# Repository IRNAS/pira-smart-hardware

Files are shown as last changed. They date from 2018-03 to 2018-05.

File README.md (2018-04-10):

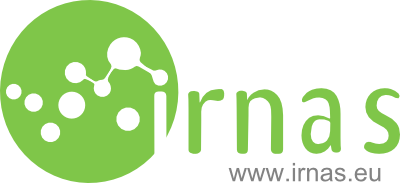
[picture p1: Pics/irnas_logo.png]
irnas_logo

# PiRa Smart
## Power in Responsive Applications HAT for Raspberry Pi with BLE, LoRa and RTC for power saving mode
PiRa Smart is a next generation compact shield for power scheduling on Rasppbery Pi and similar devices with solar and wirelessly powered applications.

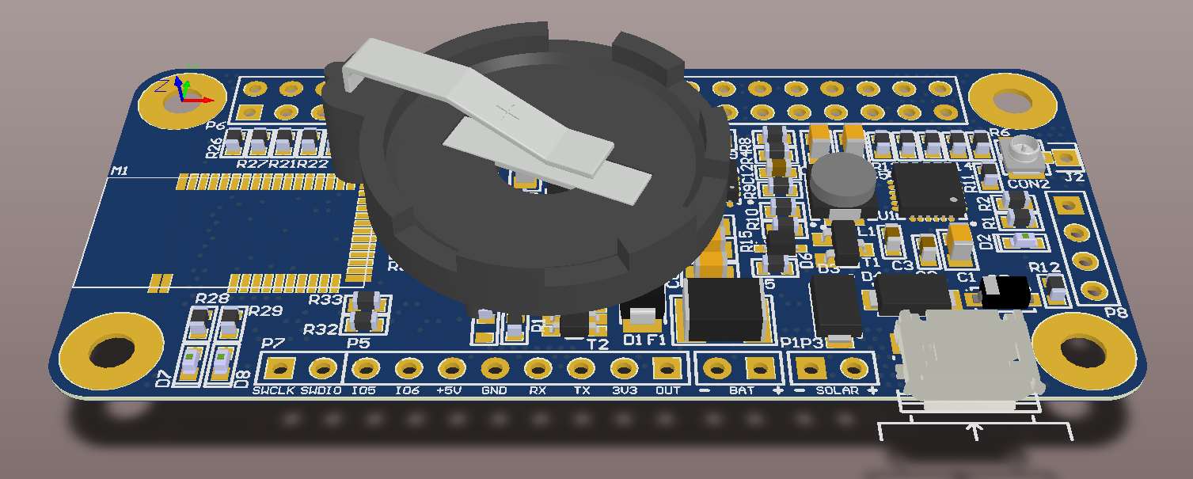
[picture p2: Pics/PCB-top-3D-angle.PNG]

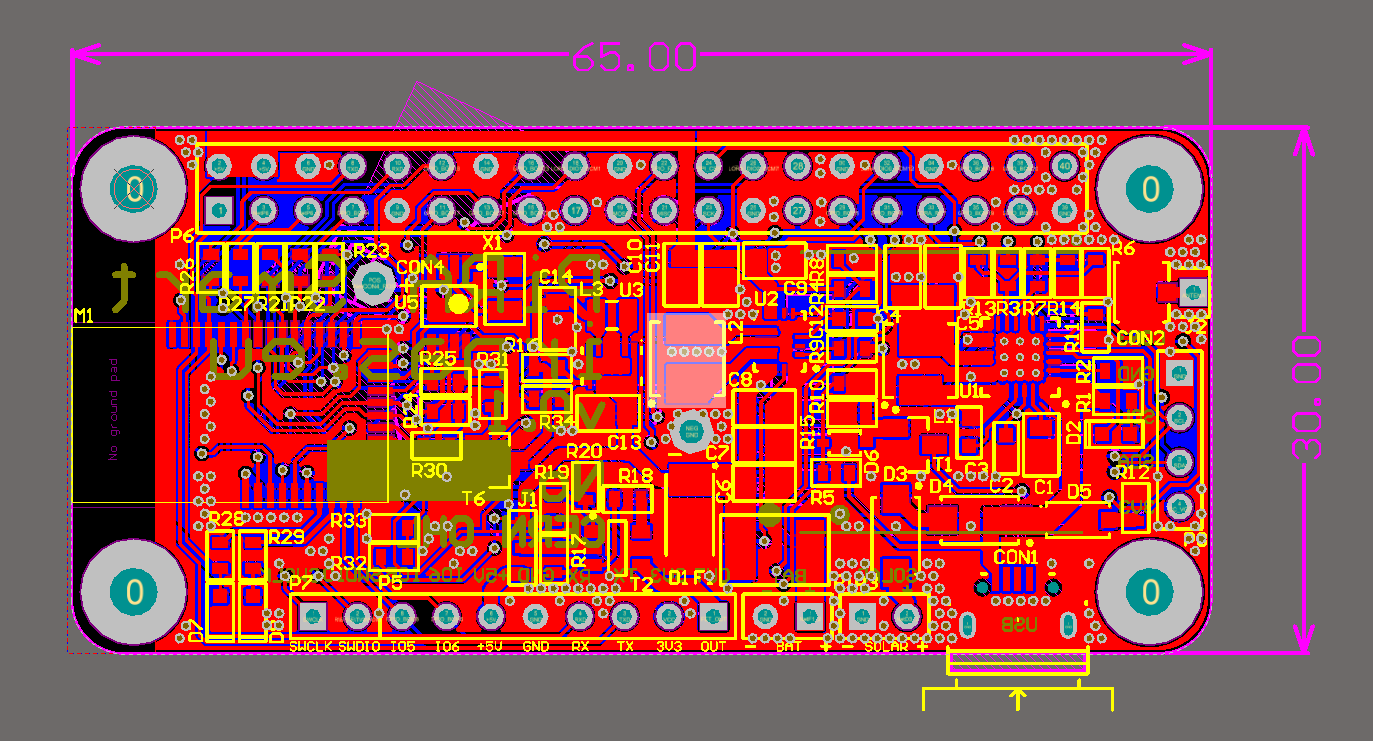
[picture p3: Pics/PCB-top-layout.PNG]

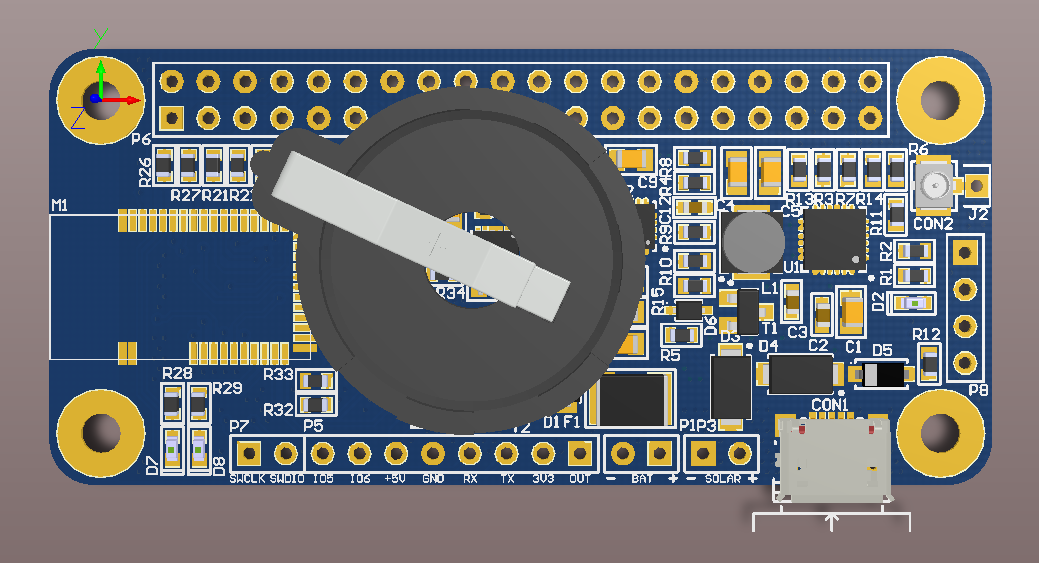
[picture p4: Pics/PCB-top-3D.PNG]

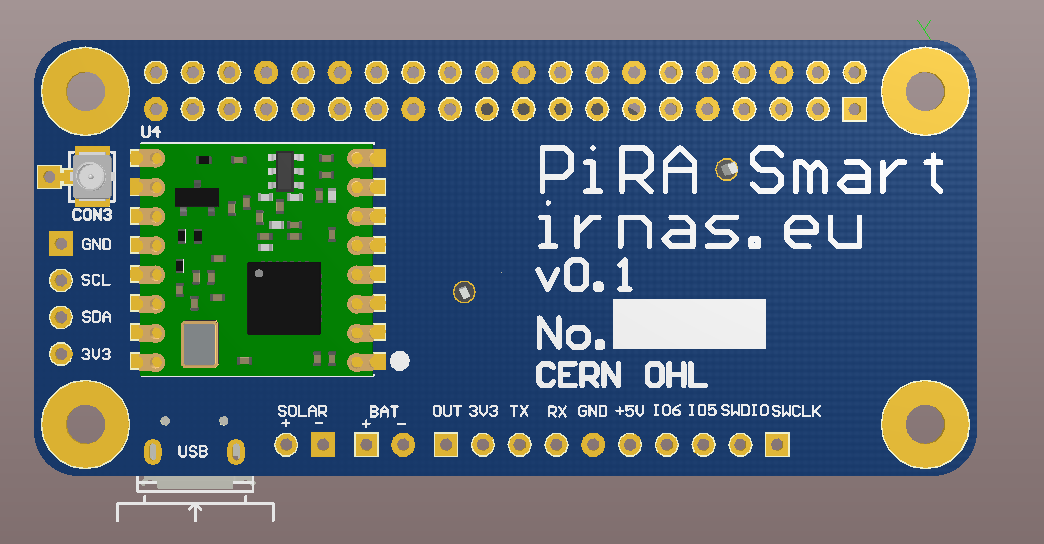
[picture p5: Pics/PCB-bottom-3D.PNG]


## Features

* Single cell LiPo cell charging of up to 3A (multiple 18650 cells supported) + LifePo4 support
* Solar panel charging (Voltaic systems 6W panels in parallel recommended)
* USB charging, compatible with QI wireless chargers
* Advanced current limiting, to support wide array of chargers
* Precise charging control via i2c (BQ24296)
* Battery temperature protection with thermistor
* Battery reverse polarity protection and fuse (3A)
* High-current battery output mosfet (for 3G or satellite modems)
* LoRa RMF95 communication module
* Nordic nRF51822 based BLE device for FOTA (Firmware Over-The-Air update) and control (MDBT40)
* Advanced power scheduling for robust applications:
  * ISL1208 RTC for configurable scheduled boot and timekeeping, with battery backup power supply to save power of the main battery
  * configurable power-up sources (RTC, charging, etc.)
 
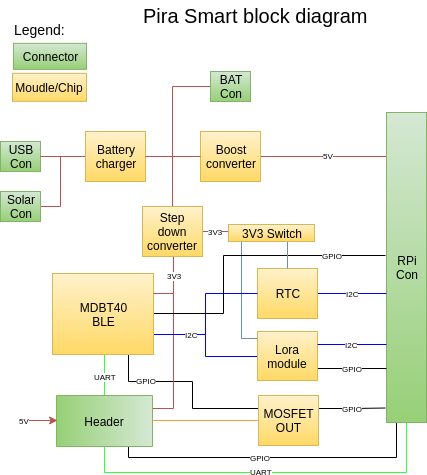
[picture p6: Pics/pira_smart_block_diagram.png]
pira_block_diagram


## Connector pinout

 * All ground pins connected
 * Pin 1 -  3V3 - Not Used
 * Pin 2 -  5V - From board to Pi
 * Pin 3 -  SDA - Connected to MDBT40 and other I2C devices through 0R resistors
 * Pin 4 -  5V - From board to Pi
 * Pin 5 -  SCL - Connected to MDBT40 and other I2C devices through 0R resistors
 * Pin 7 -  GPIO BCM 4 - Connected to MDBT40, P0.24
 * Pin 8 -  TXD - Connected to Header P5 (pin 3) and MDBT40, P0.18
 * Pin 10 - RXD - Connected to Header P5 (pin 4) and MDBT40, P0.17
 * Pin 11 - GPIO BCM 17 - Connected to MDBT40, P0.25
 * Pin 12 - GPIO BCM 18 - Connected to MDBT40, P0.30
 * Pin 13 - GPIO BCM 27 - Connected to MDBT40, P0.28
 * Pin 15 - GPIO BCM 22 - Connected to MDBT40, P0.29
 * Pin 16 - GPIO BCM 23 - GPIO-FET - Enable MOSFET output and connected to MDBT40, P0.16
 * Pin 17 - Not Connected
 * Pin 18 - GPIO BCM 1  - Connected to LoRa DIO1
 * Pin 19 - MOSI - Connected to RFM95 (LoRa) and MDBT40, P0.05
 * Pin 21 - MISO - Connected to RFM95 (LoRa) and MDBT40, P0.06
 * Pin 22 - GPIO BCM 25 - Connected to MDBT40, P0.15
 * Pin 23 - SCK  - Connected to RFM95 (LoRa) and MDBT40, P0.07
 * Pin 24 - CSS  - Connected to RFM95 (LoRa) and MDBT40, P0.14
 * Pin 26 - GPIO BCM 7 - Connected to LoRa DIO2
 * Pin 27 - Not Connected
 * Pin 28 - Not Connected
 * Pin 29 - GPIO BCM 5  - Connected to Header P5 (pin 7) and MDBT40, P0.10
 * Pin 31 - GPIO BCM 6  - Connected to Header P5 (pin 8) and MDBT40, P0.09
 * Pin 32 - GPIO BCM 12 - Connected to LoRa DIO0
 * Pin 33 - GPIO BCM 13 - LoRa RESET
 * Pin 35 - GPIO BCM 19 - Connected to MDBT40, P0.01
 * Pin 36 - GPIO BCM 16 - Connected to MDBT40, P0.02
 * Pin 37 - GPIO BCM 26 - Connected to MDBT40, P0.03
 * Pin 38 - GPIO BCM 20 - Connected to MDBT40, P0.04
 * Pin 40 - Not Connected

#### License

All our projects are as usefully open-source as possible.

Hardware including documentation is licensed under [CERN OHL v.1.2. license](http://www.ohwr.org/licenses/cern-ohl/v1.2)

Firmware and software originating from the project is licensed under [GNU GENERAL PUBLIC LICENSE v3](http://www.gnu.org/licenses/gpl-3.0.en.html).

Open data generated by our projects is licensed under [CC0](https://creativecommons.org/publicdomain/zero/1.0/legalcode).

All our websites and additional documentation are licensed under [Creative Commons Attribution-ShareAlike 4 .0 Unported License](https://creativecommons.org/licenses/by-sa/4.0/legalcode).

What this means is that you can use hardware, firmware, software and documentation without paying a royalty and knowing that you'll be able to use your version forever. You are also free to make changes but if you share these changes then you have to do so on the same conditions that you enjoy.

Koruza, GoodEnoughCNC and IRNAS are all names and marks of Institut IRNAS Rače. 
You may use these names and terms only to attribute the appropriate entity as required by the Open Licences referred to above. You may not use them in any other way and in particular you may not use them to imply endorsement or authorization of any hardware that you design, make or sell.

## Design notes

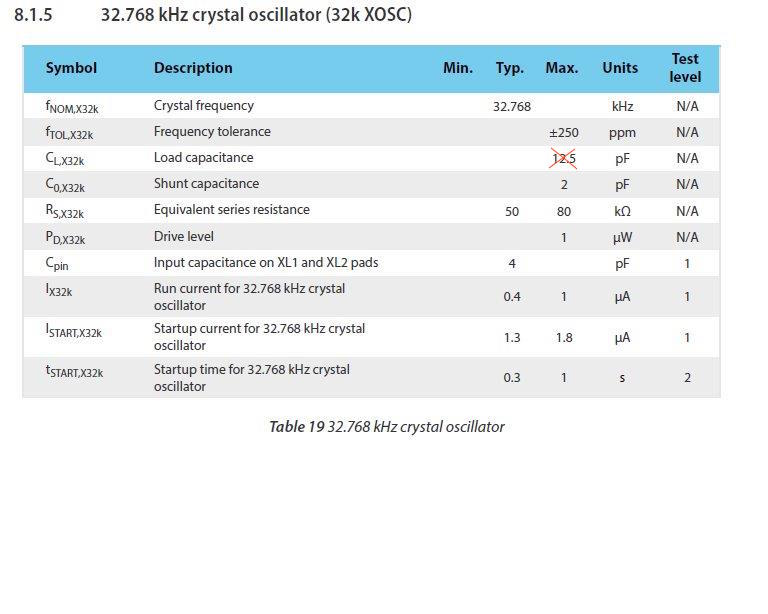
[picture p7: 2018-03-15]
docs/footprint/MDBT40_MDBT40-P Footprint_Design Guide-20170726/Recommended 32.768KHZ Crystal Spec/Nordic Spec Sheet-32.768KHZ.jpg

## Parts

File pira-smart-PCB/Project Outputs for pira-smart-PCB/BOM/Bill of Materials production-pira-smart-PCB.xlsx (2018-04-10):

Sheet: Part List Report
 | Component list |  |  | PiRa-Smart
 | Source Data From: | pira-smart-PCB.PrjPcb |  |  | Contact:
 | Project: | pira-smart-PCB.PrjPcb
 | Variant: | None |  |  |  |  |  |  | IRNAS
 | Report Date: | 4/4/2018 | 12:13:49 PM |  |  |  |  |  | www.irnas.eu
 | Print Date: | 2018-04-04 | 12:14:01
# | Manufacturer Part Number 1 | Manufacturer 1 | Description | Footprint | Designator | Quantity | Supplier 1 | Supplier Part Number 1 | Supplier Order Qty 1 | Supplier Stock 1 | Supplier Unit Price 1 | Supplier Subtotal 1 | Supplier Currency 1
1 | SE30AFG-M3/6A (https://octopart-clicks.com/click/altium?sku=2313878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) | Vishay Semiconductors (https://octopart-clicks.com/click/altium?sku=2313878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) | VISHAY - SE30AFG-M3/6A - RECTIFIER, ESD, 400V, 3A, DO-221AC | SODFL127P600-8N | D3, D4 | 2 | Farnell | 2313878 (https://octopart-clicks.com/click/altium?sku=2313878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) | 8 | 557 | 0.17 | 1.34 | GBP
2 | RS1JE361T (https://octopart-clicks.com/click/altium?sku=9550143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) | Vishay Intertechnology (https://octopart-clicks.com/click/altium?sku=9550143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) | VISHAY - RS1J-E3/61T.. - DIODE, FAST, 1A, 600V, SMD | SMC/DO-214AC | D1 | 1 | Farnell | 9550143 (https://octopart-clicks.com/click/altium?sku=9550143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) | 5 | 5074 | 0.21 | 1.05 | GBP
3 | RCA060310R0FKEA (https://octopart-clicks.com/click/altium?sku=2616585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) | Vishay Dale (https://octopart-clicks.com/click/altium?sku=2616585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) | VISHAY - RCA060310R0FKEA - RES, AUTO, THICK FILM, 10R, 1%, 0603 | RES0603 | R12 | 1 | Farnell | 2616585 (https://octopart-clicks.com/click/altium?sku=2616585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) | 10 | 326 | 0.09 | 0.92 | EUR
4 | BQ24296RGET (https://octopart-clicks.com/click/altium?sku=2373541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) | Texas Instruments (https://octopart-clicks.com/click/altium?sku=2373541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) | IC LI+ CHARGER PWR MGMT 24VQFN | QFN4x4 | U1 | 1 | Farnell | 2373541 (https://octopart-clicks.com/click/altium?sku=2373541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) | 4 | 251 | 2.36 | 9.44 | EUR
5 | TPS630701RNMT (https://octopart-clicks.com/click/altium?sku=2643432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) | Texas Instruments (https://octopart-clicks.com/click/altium?sku=2643432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) | TEXAS INSTRUMENTS - TPS630701RNMT - DC/DC CONV, BUCK-BOOST, 2.4MHZ, VQFN-15 | VQFN TPS | U2 | 1 | Farnell | 2643432 (https://octopart-clicks.com/click/altium?sku=2643432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) | 4 | 170 | 2.58 | 10.32 | EUR
6 | TPS62740DSSR (https://octopart-clicks.com/click/altium?sku=2781752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) | Texas Instruments (https://octopart-clicks.com/click/altium?sku=2781752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) | Voltage Regulators - Switching Regulators 360-nA Iq SD Cnvtr w/ Intg Load Switch | SON50P200X265_HS-13N | U3 | 1 | Farnell | 2781752 (https://octopart-clicks.com/click/altium?sku=2781752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) | 5 | 2312 | 1.44 | 7.20 | EUR
7 | 109990166 (https://octopart-clicks.com/click/altium?sku=1597-1488-ND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) | Seeed Studio (https://octopart-clicks.com/click/altium?sku=1597-1488-ND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) | RFM95 ULTRA-LONG RANGE TRANSCEIV | Lora_module1 | U4 | 1 | Digi-Key | 1597-1488-ND (https://octopart-clicks.com/click/altium?sku=1597-1488-ND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) |  | 0 |  |  | Loading...
8 | MMBT3904 (https://octopart-clicks.com/click/altium?manufacturer=ON%20Semiconductor%20%2F%20Fairchild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) | ON Semiconductor / Fairchild (https://octopart-clicks.com/click/altium?manufacturer=ON%20Semiconductor%20%2F%20Fairchild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) | ON SEMICONDUCTOR/FAIRCHILD - MMBT3904 - TRANSISTOR, NPN, SOT-23 | SOT23127P600-8N | T1 | 1 | Farnell | 9846727 (https://octopart-clicks.com/click/altium?manufacturer=ON%20Semiconductor%20%2F%20Fairchild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) | 5 | 0 | 0.15 | 0.77 | GBP
9 | 2N7002,215 (https://octopart-clicks.com/click/altium?sku=1510761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) | Nexperia (https://octopart-clicks.com/click/altium?sku=1510761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) | NEXPERIA - 2N7002,215 - MOSFET,N CH, 60V,0.3A,SOT23 | SOT23127P600-8N | T6 | 1 | Farnell | 1510761 (https://octopart-clicks.com/click/altium?sku=1510761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) | 5 | 0 | 0.07 | 0.33 | GBP
10 | FDSD0420-H-1R5M=P3 (https://octopart-clicks.com/click/altium?sku=2530091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) | Murata (https://octopart-clicks.com/click/altium?sku=2530091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) | MURATA - FDSD0420-H-1R5M=P3 - INDUCTOR, SHIELDED, 1.5UH, 5.1A, 20% | FDSD0402 | L1, L2 | 2 | Farnell | 2530091 (https://octopart-clicks.com/click/altium?sku=2530091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) | 8 | 1228 | 0.89 | 7.10 | EUR
11 | GRM188R61C475KAAJD (https://octopart-clicks.com/click/altium?sku=2611924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) | Murata (https://octopart-clicks.com/click/altium?sku=2611924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) | MURATA - GRM188R61C475KAAJD - CAP, MLCC, X5R, 4.7UF, 16V, 0603 | CAP0603 | C2 | 1 | Farnell | 2611924 (https://octopart-clicks.com/click/altium?sku=2611924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) | 10 | 210 | 0.25 | 2.48 | GBP
12 | MC0805X106K160CT, MC0805X106K160CT, MC0805X106K160CT, MC0805X106K160CT, MC0805X106K160CT, CGA4J1X5R1C106K125AC, CGA4J1X5R1C106K125AC (https://octopart-clicks.com/click/altium?seller=Farnell&country=US&channel=BOM%20Report) | Multicomp, Multicomp, Multicomp, Multicomp, Multicomp, TDK, TDK (https://octopart-clicks.com/click/altium?seller=Farnell&country=US&channel=BOM%20Report) | TDK - CGA4J1X5R1C106K125AC - CAP, MLCC, X5R, 10UF, 16V, 0805 | CAP0805 | C1, C4, C5, C6, C11, C13, C14 | 7 | Farnell | 2320856, 2320856, 2320856, 2320856, 2320856, 2210948RL, 2210948RL (https://octopart-clicks.com/click/altium?seller=Farnell&country=US&channel=BOM%20Report) |  |  |  |  | GBP
13 | MCWR06X2493FTL (https://octopart-clicks.com/click/altium?sku=2447306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) | Multicomp (https://octopart-clicks.com/click/altium?sku=2447306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) | MULTICOMP MCWR06X2493FTL SMD Chip Resistor, Thick Film, 249 kohm, 50 V, 0603 [1608 Metric], 100 mW, 1%, MCWR Series | RES0603 | R32 | 1 | Farnell | 2447306 (https://octopart-clicks.com/click/altium?sku=2447306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) | 10 | 4967 | 0.0031 | 0.03 | GBP
14 | MCWR06X1000FTL (https://octopart-clicks.com/click/altium?sku=2447227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) | Multicomp (https://octopart-clicks.com/click/altium?sku=2447227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) | MULTICOMP - MC0063W06031100R - RES, THICK FILM, 100R, 1%, 0.063W, 0603 | RES0603 | R18, R19, R30 | 3 | Farnell | 2447227 (https://octopart-clicks.com/click/altium?sku=2447227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) | 12 | 202531 | 0.0031 | 0.04 | GBP
15 | MC0603B473K500CT (https://octopart-clicks.com/click/altium?sku=1759116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) | Multicomp (https://octopart-clicks.com/click/altium?sku=1759116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) | MULTICOMP - MC0603B473K500CT - CAP, MLCC, X7R, 47NF, 50V, 0603 | CAP0603 | C3 | 1 | Farnell | 1759116 (https://octopart-clicks.com/click/altium?sku=1759116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) | 10 | 17118 | 0.02 | 0.16 | GBP
16 | MC0805X226M6R3CT (https://octopart-clicks.com/click/altium?sku=1759415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) | Multicomp (https://octopart-clicks.com/click/altium?sku=1759415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) | MULTICOMP - MC0805X226M6R3CT - CAP, MLCC, X5R, 22UF, 0805 | CAP0805 | C7, C8, C9, C10 | 4 | Farnell | 1759415 (https://octopart-clicks.com/click/altium?sku=1759415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) | 20 | 7375 | 0.14 | 2.84 | GBP
17 | MCMR06X103JTL (https://octopart-clicks.com/click/altium?sku=2073356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) | Multicomp (https://octopart-clicks.com/click/altium?sku=2073356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) | MULTICOMP - MCMR06X103 JTL - RES, CERAMIC, 10K, 5%, 0.1W, 0603 | RES0603 | R6, R9, R10, R15, R21, R22, R23 | 7 | Farnell | 2073356 (https://octopart-clicks.com/click/altium?sku=2073356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) | 28 | 8369 | 0.01 | 0.19 | EUR
18 | MCMR06X104JTL (https://octopart-clicks.com/click/altium?sku=2073357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) | Multicomp (https://octopart-clicks.com/click/altium?sku=2073357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) | MULTICOMP - MCMR06X104 JTL - RES, CERAMIC, 100K, 5%, 0.1W, 0603 | RES0603 | R16, R17, R20, R31, R33 | 5 | Farnell | 2073357 (https://octopart-clicks.com/click/altium?sku=2073357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) | 20 | 6564 | 0.01 | 0.13 | EUR
19 | MCMR06X4701FTL (https://octopart-clicks.com/click/altium?sku=2073509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) | Multicomp (https://octopart-clicks.com/click/altium?sku=2073509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) | MULTICOMP - MCMR06X4701FTL - RES, CERAMIC, 4K7, 1%, 0.1W, 0603 | RES0603 | R24, R25 | 2 | Farnell | 2073509 (https://octopart-clicks.com/click/altium?sku=2073509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) | 10 | 58910 | 0.01 | 0.08 | GBP
20 | MCMR06X471JTL (https://octopart-clicks.com/click/altium?sku=2073513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) | Multicomp (https://octopart-clicks.com/click/altium?sku=2073513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) | MULTICOMP - MCMR06X471 JTL - RES, CERAMIC, 470R, 5%, 0.1W, 0603 | RES0603 | R1, R14, R28, R29 | 4 | Farnell | 2073513 (https://octopart-clicks.com/click/altium?sku=2073513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) | 16 | 745 | 0.01 | 0.14 | EUR
21 | MCMR06X5601FTL (https://octopart-clicks.com/click/altium?sku=2073537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) | Multicomp (https://octopart-clicks.com/click/altium?sku=2073537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) | MULTICOMP - MCMR06X5601FTL - RES, CERAMIC, 5K6, 1%, 0.1W, 0603 | RES0603 | R3 | 1 | Farnell | 2073537 (https://octopart-clicks.com/click/altium?sku=2073537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) | 10 | 8340 | 0.01 | 0.09 | EUR
22 | MCWR06X1503FTL (https://octopart-clicks.com/click/altium?sku=2447254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) | Multicomp (https://octopart-clicks.com/click/altium?sku=2447254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) | MULTICOMP - MCWR06X1503FTL - RES, THICK FILM, 150KOHM, 1%, 0.1W | RES0603 | R8 | 1 | Farnell | 2447254 (https://octopart-clicks.com/click/altium?sku=2447254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) | 10 | 1280 | 0.003 | 0.03 | GBP
23 | MCWR06X2200FTL (https://octopart-clicks.com/click/altium?sku=2447298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) | Multicomp (https://octopart-clicks.com/click/altium?sku=2447298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) | MULTICOMP - MCWR06X2200FTL - RES, THICK FILM, 220R, 1%, 0.1W, 0603 | RES0603 | R7 | 1 | Farnell | 2447298 (https://octopart-clicks.com/click/altium?sku=2447298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) | 10 | 102020 | 0.0031 | 0.03 | GBP
24 | MCWR06X3302FTL (https://octopart-clicks.com/click/altium?sku=2447342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) | Multicomp (https://octopart-clicks.com/click/altium?sku=2447342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) | MULTICOMP - MCWR06X3302FTL - RES, THICK FILM, 33K, 1%, 0.1W, 0603 | RES0603 | R13 | 1 | Farnell | 2447342 (https://octopart-clicks.com/click/altium?sku=2447342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) | 10 | 91916 | 0.003 | 0.03 | GBP
25 | MCWR06X3901FTL (https://octopart-clicks.com/click/altium?sku=2447363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) | Multicomp (https://octopart-clicks.com/click/altium?sku=2447363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) | MULTICOMP - MCWR06X3901FTL - RES, THICK FILM, 3K9, 1%, 0.1W, 0603 | RES0603 | R5 | 1 | Farnell | 2447363 (https://octopart-clicks.com/click/altium?sku=2447363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) | 10 | 62070 | 0.0031 | 0.03 | GBP
26 | Loading... (https://octopart-clicks.com/click/altium?sku=2688519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) | Loading... (https://octopart-clicks.com/click/altium?sku=2688519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) | MURATA - GRM188R71C104KA01J - CAP, MLCC, X7R, 0.1UF, 16V, 0603 | CAP0603 | C12 | 1 | Farnell | 2688519 (https://octopart-clicks.com/click/altium?sku=2688519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) |  |  |  |  | Loading...
27 | Loading... (https://octopart-clicks.com/click/altium?sku=2463510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) | Loading... (https://octopart-clicks.com/click/altium?sku=2463510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) | ON SEMICONDUCTOR - MM3Z3V0T1G - ZENER DIODE, 200MW, 3V, SOD-323 | SOD-323 2L | D6 | 1 | Farnell | 2463510 (https://octopart-clicks.com/click/altium?sku=2463510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) |  |  |  |  | Loading...
28 | MINISMDC150F/24-2 (https://octopart-clicks.com/click/altium?sku=1345929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) | Littelfuse (https://octopart-clicks.com/click/altium?sku=1345929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) | LITTELFUSE - MINISMDC150F/24-2 - POLYSWITCH, SMD, 1812, 1.5A | Chip2PinSM127P600-8N | F1 | 1 | Farnell | 1345929 (https://octopart-clicks.com/click/altium?sku=1345929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) | 4 | 10565 | 0.46 | 1.82 | GBP
29 | 1066 (https://octopart-clicks.com/click/altium?sku=2293258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) | Keystone Electronics (https://octopart-clicks.com/click/altium?sku=2293258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) | HOLDER BATT COIN COMPACT 20MM | 1066_1066(Primary) | CON4 | 1 | Farnell | 2293258 (https://octopart-clicks.com/click/altium?sku=2293258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) | 4 | 16639 | 1.00 | 4.00 | EUR
30 | LFXTAL009678 (https://octopart-clicks.com/click/altium?sku=2449398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) | IQD (https://octopart-clicks.com/click/altium?sku=2449398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) | CRYSTAL, 32.768KHZ, 12.5PF, SMD | LFXTAL009678 | X1 | 1 | Farnell | 2449398 (https://octopart-clicks.com/click/altium?sku=2449398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) | 5 | 6844 | 0.22 | 1.10 | GBP
31 | ISL1208IU8Z-T7A (https://octopart-clicks.com/click/altium?sku=2543322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) | Intersil (https://octopart-clicks.com/click/altium?sku=2543322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) | IC RTC/CALENDAR I2C LP 8MSOP | TSOP65P500X110-8N | U5 | 1 | Farnell | 2543322 (https://octopart-clicks.com/click/altium?sku=2543322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) | 4 | 316 | 2.63 | 10.52 | EUR
32 | U.FL-R-SMT-1(10) (https://octopart-clicks.com/click/altium?sku=1688077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) | Hirose (https://octopart-clicks.com/click/altium?sku=1688077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) | HIROSE(HRS) - U.FL-R-SMT-1(10) - RF COAXIAL, U.FL, STRAIGHT JACK, 50OHM | uFL SMD connector | CON2, CON3 | 2 | Farnell | 1688077 (https://octopart-clicks.com/click/altium?sku=1688077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) | 10 | 37595 | 0.49 | 4.90 | GBP
33 | BZT52C6V2 (https://octopart-clicks.com/click/altium?sku=1902438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) | Diodes Zetex (https://octopart-clicks.com/click/altium?sku=1902438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) | DIODES INC. - BZT52C6V2 - DIODE, ZENER, 6.2V, 0.5W, SOD-123 | SOD123 | D5 | 1 | Farnell | 1902438 (https://octopart-clicks.com/click/altium?sku=1902438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) | 5 | 3100 | 0.66 | 3.27 | EUR
34 | DMG6602SVT (https://octopart-clicks.com/click/altium?sku=2061522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) | Diodes (https://octopart-clicks.com/click/altium?sku=2061522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) | DIODES INC. - DMG6602SVT - MOSFET, NP CH, , 30V, 3.4, ATSOT23 | TSOT26 | T2 | 1 | Farnell | 2061522 (https://octopart-clicks.com/click/altium?sku=2061522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) | 5 | 0 | 0.28 | 1.43 | GBP
35 | HSMS-C190 (https://octopart-clicks.com/click/altium?sku=2497356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) | Broadcom Avago (https://octopart-clicks.com/click/altium?sku=2497356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) | BROADCOM LIMITED - HSMS-C190 - LED, RED, 10MCD, 626NM | LED0603 | D2, D7, D8 | 3 | Farnell | 2497356 (https://octopart-clicks.com/click/altium?sku=2497356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) |  | 11495 |  |  | Loading...
36 | CR0603-J/-000ELF (https://octopart-clicks.com/click/altium?sku=2008343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) | Bourns (https://octopart-clicks.com/click/altium?sku=2008343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) | BOURNS - CR0603-J/-000ELF - RES, THICK FILM, 0R, 5%, 0.1W, 0603 | RES0603 | R2, R4, R11, R26, R27, R34 | 6 | Farnell | 2008343 (https://octopart-clicks.com/click/altium?sku=2008343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) | 24 | 9770 | 0.01 | 0.36 | GBP
37 |  |  | Fixed Inductors PFL2015 Shld Power 2.2 uH 20 % 1 A | INDC2214X15N | L3 | 1 | Farnell
38 |  |  | Header, 4-Pin | HDR1X4 | P8 | 1
39 |  |  | Jumper | JUMPER_NC | J1 | 1
40 |  |  | MDBT40 | PCB_MDBT40_10X18 | M1 | 1
 |  |  |  |  |  | 75 |  |  | 301 |  |  | 72.1605
Approved |  |  |  | Notes
 |  |  |  | pcs: |  | 4 |  | Total |  | 72.1605 |  | <none>
 |  |  |  |  |  |  |  | Price for 1pcs |  | 18.04 |  | <none>

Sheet: Project Information
Project Full Path | C:\Users\Goran\Documents\Repositories\pira-smart-hardware\pira-smart-PCB\pira-smart-PCB.PrjPcb
Project Filename | pira-smart-PCB.PrjPcb
Variant Name | None
Data-Source Filename | pira-smart-PCB.PrjPcb
Data-Source Full Path | C:\Users\Goran\Documents\Repositories\pira-smart-hardware\pira-smart-PCB\pira-smart-PCB.PrjPcb
Title | Bill of Materials production For Project [pira-smart-PCB.PrjPcb] (No PCB Document Selected)
Total Quantity | 75
Report Time | 12:13:49 PM
Report Date | 4/4/2018
Report Date & Tine | 4/4/2018 12:13:49 PM
Output Name | Bill of Materials production
Output Type | BOM_PartType
Output Generator Name | BOM
Output Generator Description | Bill of Materials

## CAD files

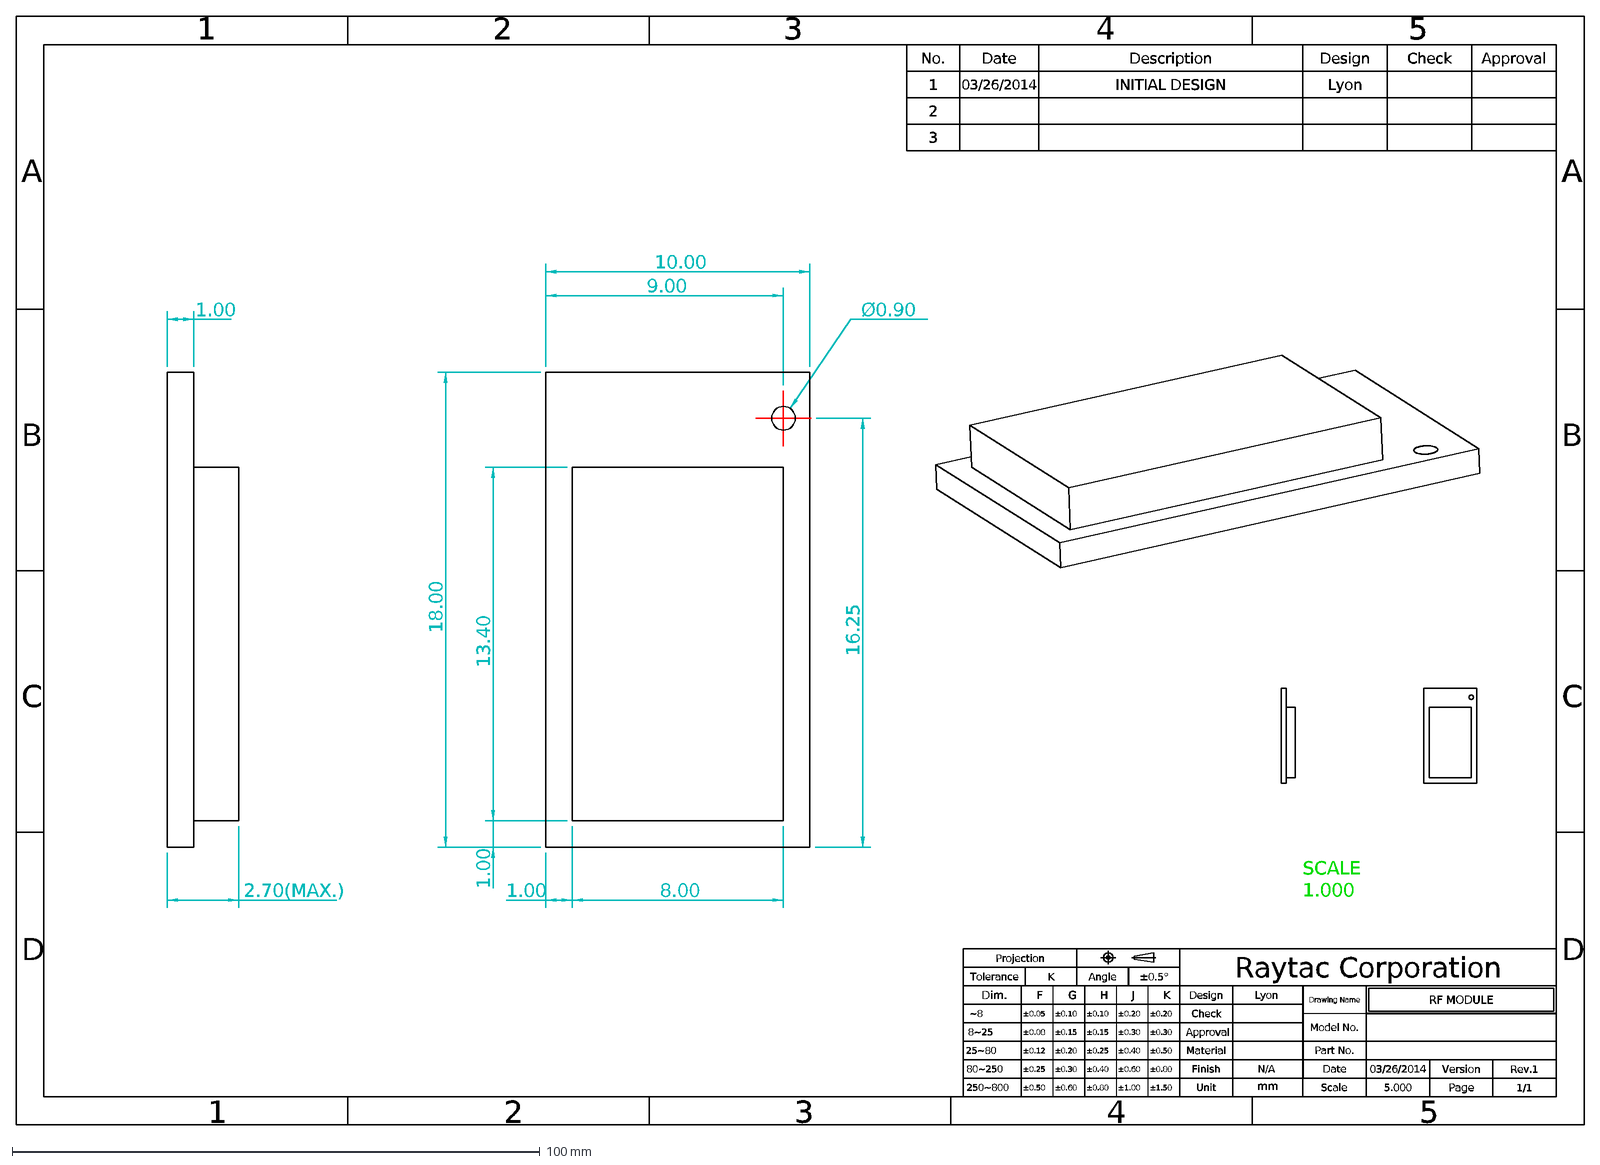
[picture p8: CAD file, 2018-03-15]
docs/footprint/MDBT40_MDBT40-P Footprint_Design Guide-20170726/2D & 3D Drawing/MDBT40-P/MDBT40-P 2D Drawing-20150402.dxf
3
D
1
C
2
B
A
±0.50
±0.25
±0.12
±0.08
±0.05
250~800
25~80
8~25
80~250
~8
Dim.
F
±1.50
±1.00
±0.80
±0.60
4
±0.30
±0.20
K
±0.10
±0.15
±0.40
G
H
J
5
Raytac Corporation
Projection
Tolerance
Unit
mm
Angle
Finish
Material
Check
Approval
Design
Page
Scale
Drawing Name
Model No.
Date
Part No.
Version
10.00
18.00
8.00
1.00
9.00
16.25
13.40
2.70(MAX.)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

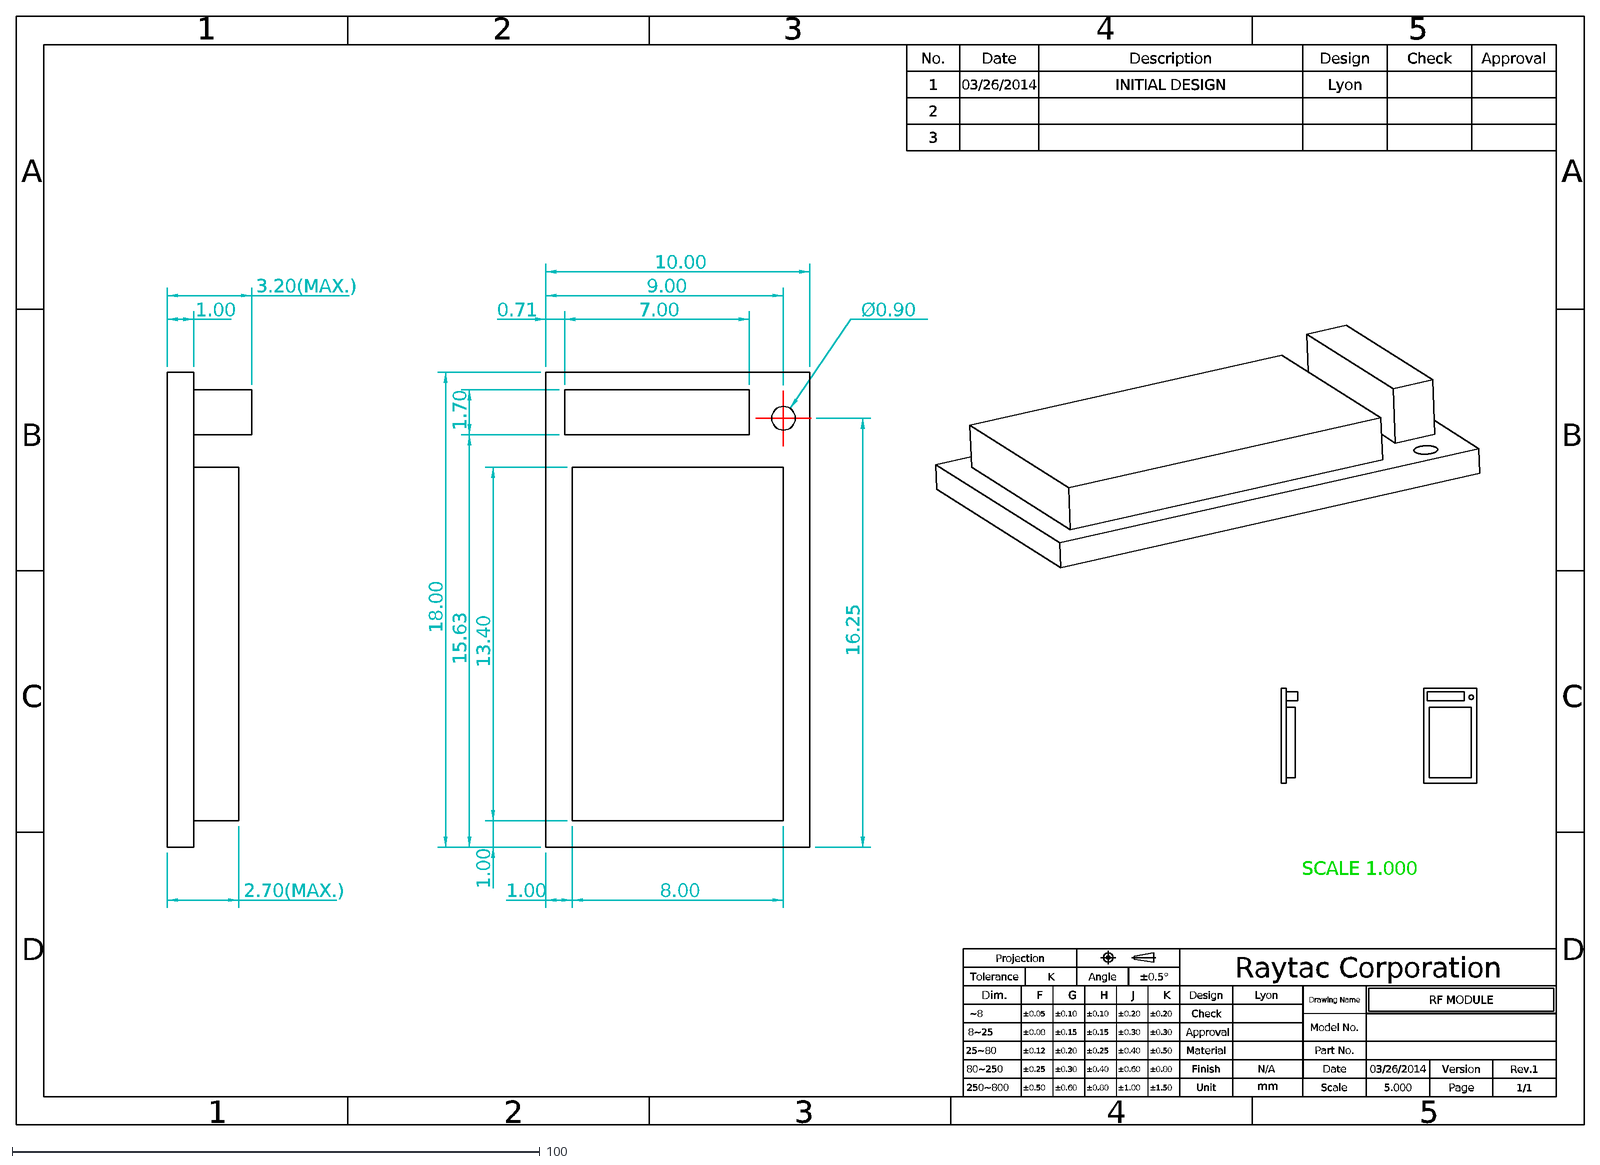
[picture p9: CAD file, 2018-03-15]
docs/footprint/MDBT40_MDBT40-P Footprint_Design Guide-20170726/2D & 3D Drawing/MDBT40/MDBT40-2D Drawing-20150402.dxf
3
D
1
C
2
B
A
±0.50
±0.25
±0.12
±0.08
±0.05
250~800
25~80
8~25
80~250
~8
Dim.
F
±1.50
±1.00
±0.80
±0.60
4
±0.30
±0.20
K
±0.10
±0.15
±0.40
G
H
J
5
Raytac Corporation
Projection
Tolerance
Unit
mm
Angle
Finish
Material
Check
Approval
Design
Page
Scale
Drawing Name
Model No.
Date
Part No.
Version
10.00
18.00
8.00
1.00
15.63
1.70
7.00
0.71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

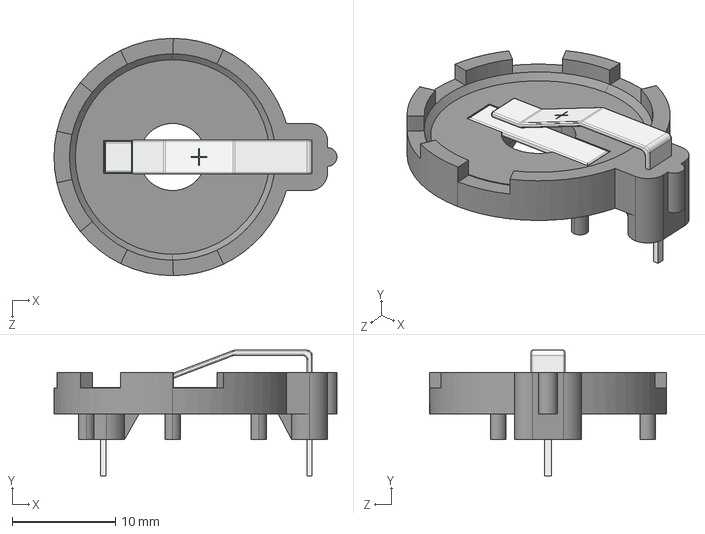
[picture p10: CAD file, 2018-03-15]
pira-smart-PCB/step/User Library-20mm_coin_holder.step
27.4 x 12.2 x 23.0 mm

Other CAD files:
docs/footprint/MDBT40_MDBT40-P Footprint_Design Guide-20170726/2D & 3D Drawing/MDBT40-P/MDBT40-P 2D Drawing-20150402.dwg
docs/footprint/MDBT40_MDBT40-P Footprint_Design Guide-20170726/2D & 3D Drawing/MDBT40/MDBT40-2D Drawing-20150402.dwg

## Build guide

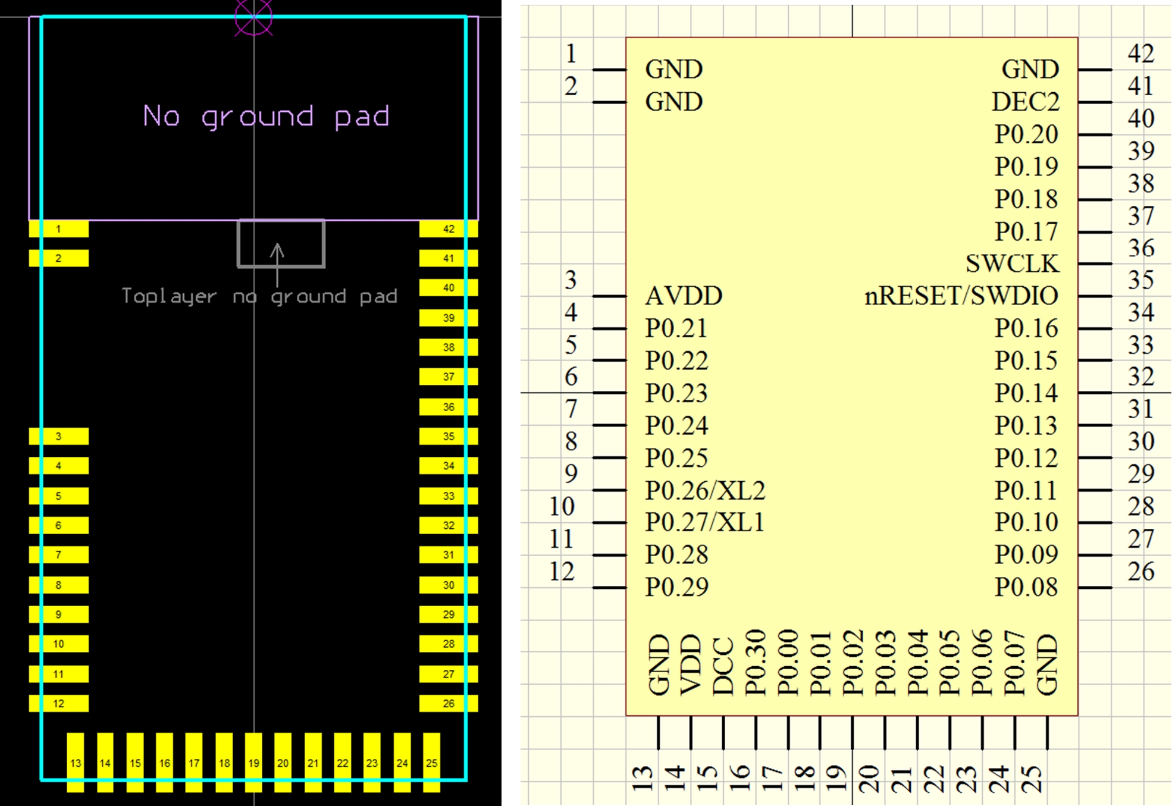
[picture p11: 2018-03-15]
docs/footprint/MDBT40_MDBT40-P Footprint_Design Guide-20170726/Footprint-2017-07-26/MDBT40_MDBT40-P Protel-170726/MDBT40 FOOTPRINT示意圖-170726.jpg

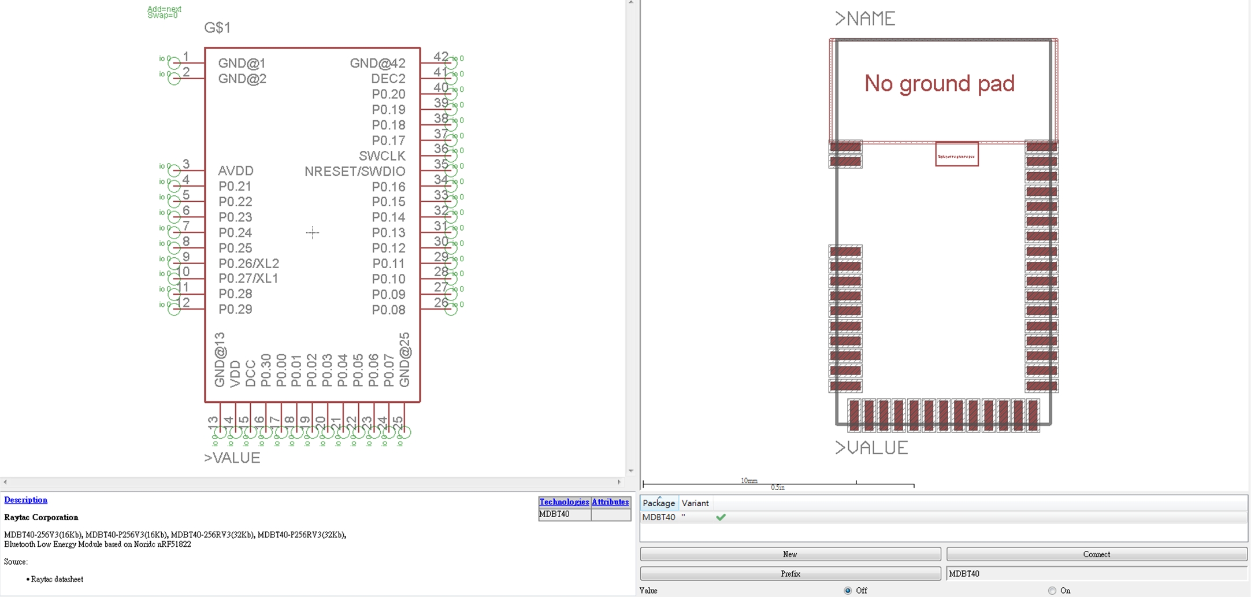
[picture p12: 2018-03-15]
docs/footprint/MDBT40_MDBT40-P Footprint_Design Guide-20170726/Footprint-2017-07-26/MDBT40_MDBT40-P Eagle-170726/MDBT40 Eagle Library-170726.jpg

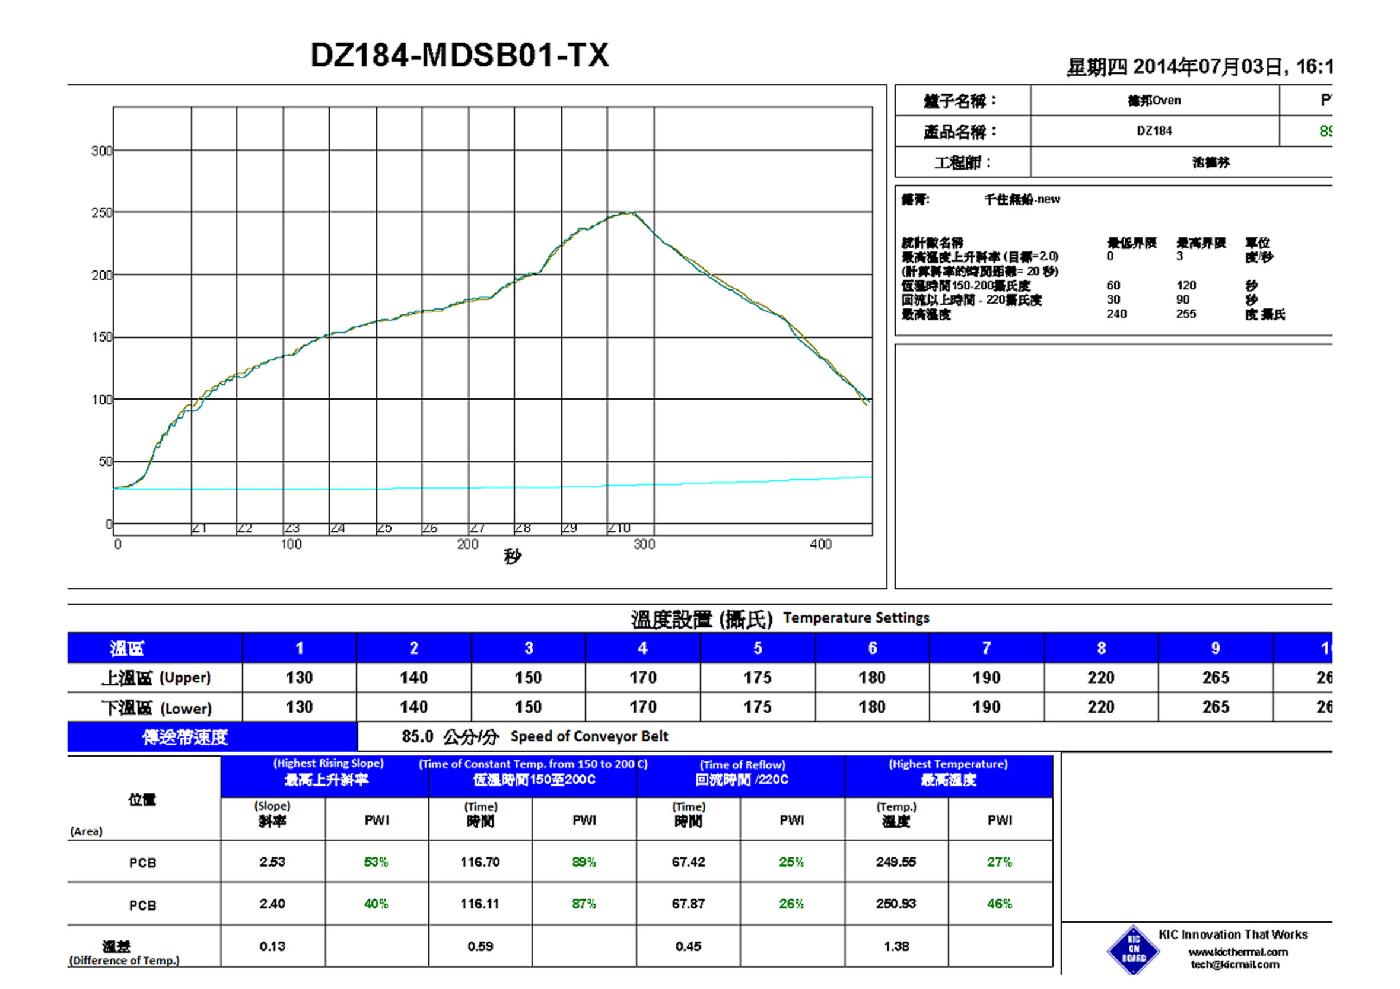
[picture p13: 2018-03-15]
docs/footprint/MDBT40_MDBT40-P Footprint_Design Guide-20170726/Module-Reflow-Reference.jpg

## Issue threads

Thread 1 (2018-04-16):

PCB markings are too small

gorankecman, 2018-04-16:
Markings on the PCB are not big enough, especially on the top layer. + and - signs for battery and solar panel connectors also need to be bigger.

gorankecman, 2018-06-07:
In version v0.2 PCB markings were enlarged. Markings are available on the bottom layer.

Closed 2018-06-07.

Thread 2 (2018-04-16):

SWDIO and SWCLK pins connected wrongly on MDBT40

gorankecman, 2018-04-16:
Pins for programming and debugging MDBT40 module are connected wrongly.
Current connection:
SWDIO -> Pin 36, SWCLK
SWCLK -> Pin 37, P0.17
Should be:
**SWDIO -> Pin 35, nRESET/SWDIO
SWCLK -> Pin 36, SWCLK**

gorankecman, 2018-06-07:
Pins are now connected correctly and programming is possible through the dedicated connector.
SWDIO -> Pin 35, nRESET/SWDIO
SWCLK -> Pin 36, SWCLK

Closed 2018-06-07.

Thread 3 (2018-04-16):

Switch on 3V3 for RTC pull up resistors and LoRa device not working

gorankecman, 2018-04-16:
When 3V3 voltage applied at input and switch turned ON from MDBT40, at the output I2C_VCC we get 1.6V. When the switch is shorted, I2C communication works.
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

gorankecman, 2018-06-07:
The proposed solution is tested and it is functional on v0.2.

Closed 2018-06-07.

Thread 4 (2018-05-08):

Fix battery holder footprint

gorankecman, 2018-05-08:
Battery holder footprint, which was imported, has top and bottom layers for a hole covered with silkscreen.
The footprint should be fixed, and an actual hole should be placed instead.

gorankecman, 2018-06-07:
Battery holder footprint was updated and pads are now correct. Change reflected on v0.2.

Closed 2018-06-07.

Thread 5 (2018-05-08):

Battery resistor divider connected to the wrong ADC input pin

gorankecman, 2018-05-08:
Battery resistor divider output connected to the pin P0.00 which is AREF0 analog input pin. This pin is used to provide the reference voltage for ADC conversion, not an analog input pin for conversion.
Battery resistor divider output should be connected to pins AN0 - AN7 or (P0.26, P0.27, and P0.01-P0.08).
This should be fixed in next version. However, as a workaround, pin P0.04 could be used instead of Power Good functionality from 3V3 power supply IC.

gorankecman, 2018-05-08:
MDBT40 pin assignment can be checked in following document:
http://www.raytac.com/download/MDBT40/MDBT40-ANT-D.pdf

gorankecman, 2018-06-07:
Battery resistor divider is connected to the correct ADC input pin - P0.00 or AIN2. Battery voltage measurement is possible and correct on PCB v0.2.

Closed 2018-06-07.

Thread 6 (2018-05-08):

Add capacitor to ADC input pin

gorankecman, 2018-05-08:
According to nRF51 Series Reference Manual, page 166
http://infocenter.nordicsemi.com/pdf/nRF51_RM_v3.0.pdf, in order to meet specified accuracy of the ADC, small resistors should be used in the divider. However, to reduce leakage current (and reduce total consumption of the board), high-value resistors will be used. Then, it is advisable to add a capacitor in parallel with the output of resistor divider (selection described in the document above) to meet the ADC accuracy.
Another option is to add a buffer (with operational amplifier), but due to space constraints, the capacitor is more desirable.

gorankecman, 2018-05-08:
This post should be useful.
https://devzone.nordicsemi.com/f/nordic-q-a/324/how-to-measure-lithium-battery-voltage

gorankecman, 2018-05-08:
After testing ADC, adding the capacitor across R33 in resistor divider has been proven to be mandatory.

gorankecman, 2018-06-07:
The capacitor was added and battery level resistor divider is correctly connected on P0.00 or AIN2. On PCB v0.2 battery level is correctly measured.

Closed 2018-06-07.

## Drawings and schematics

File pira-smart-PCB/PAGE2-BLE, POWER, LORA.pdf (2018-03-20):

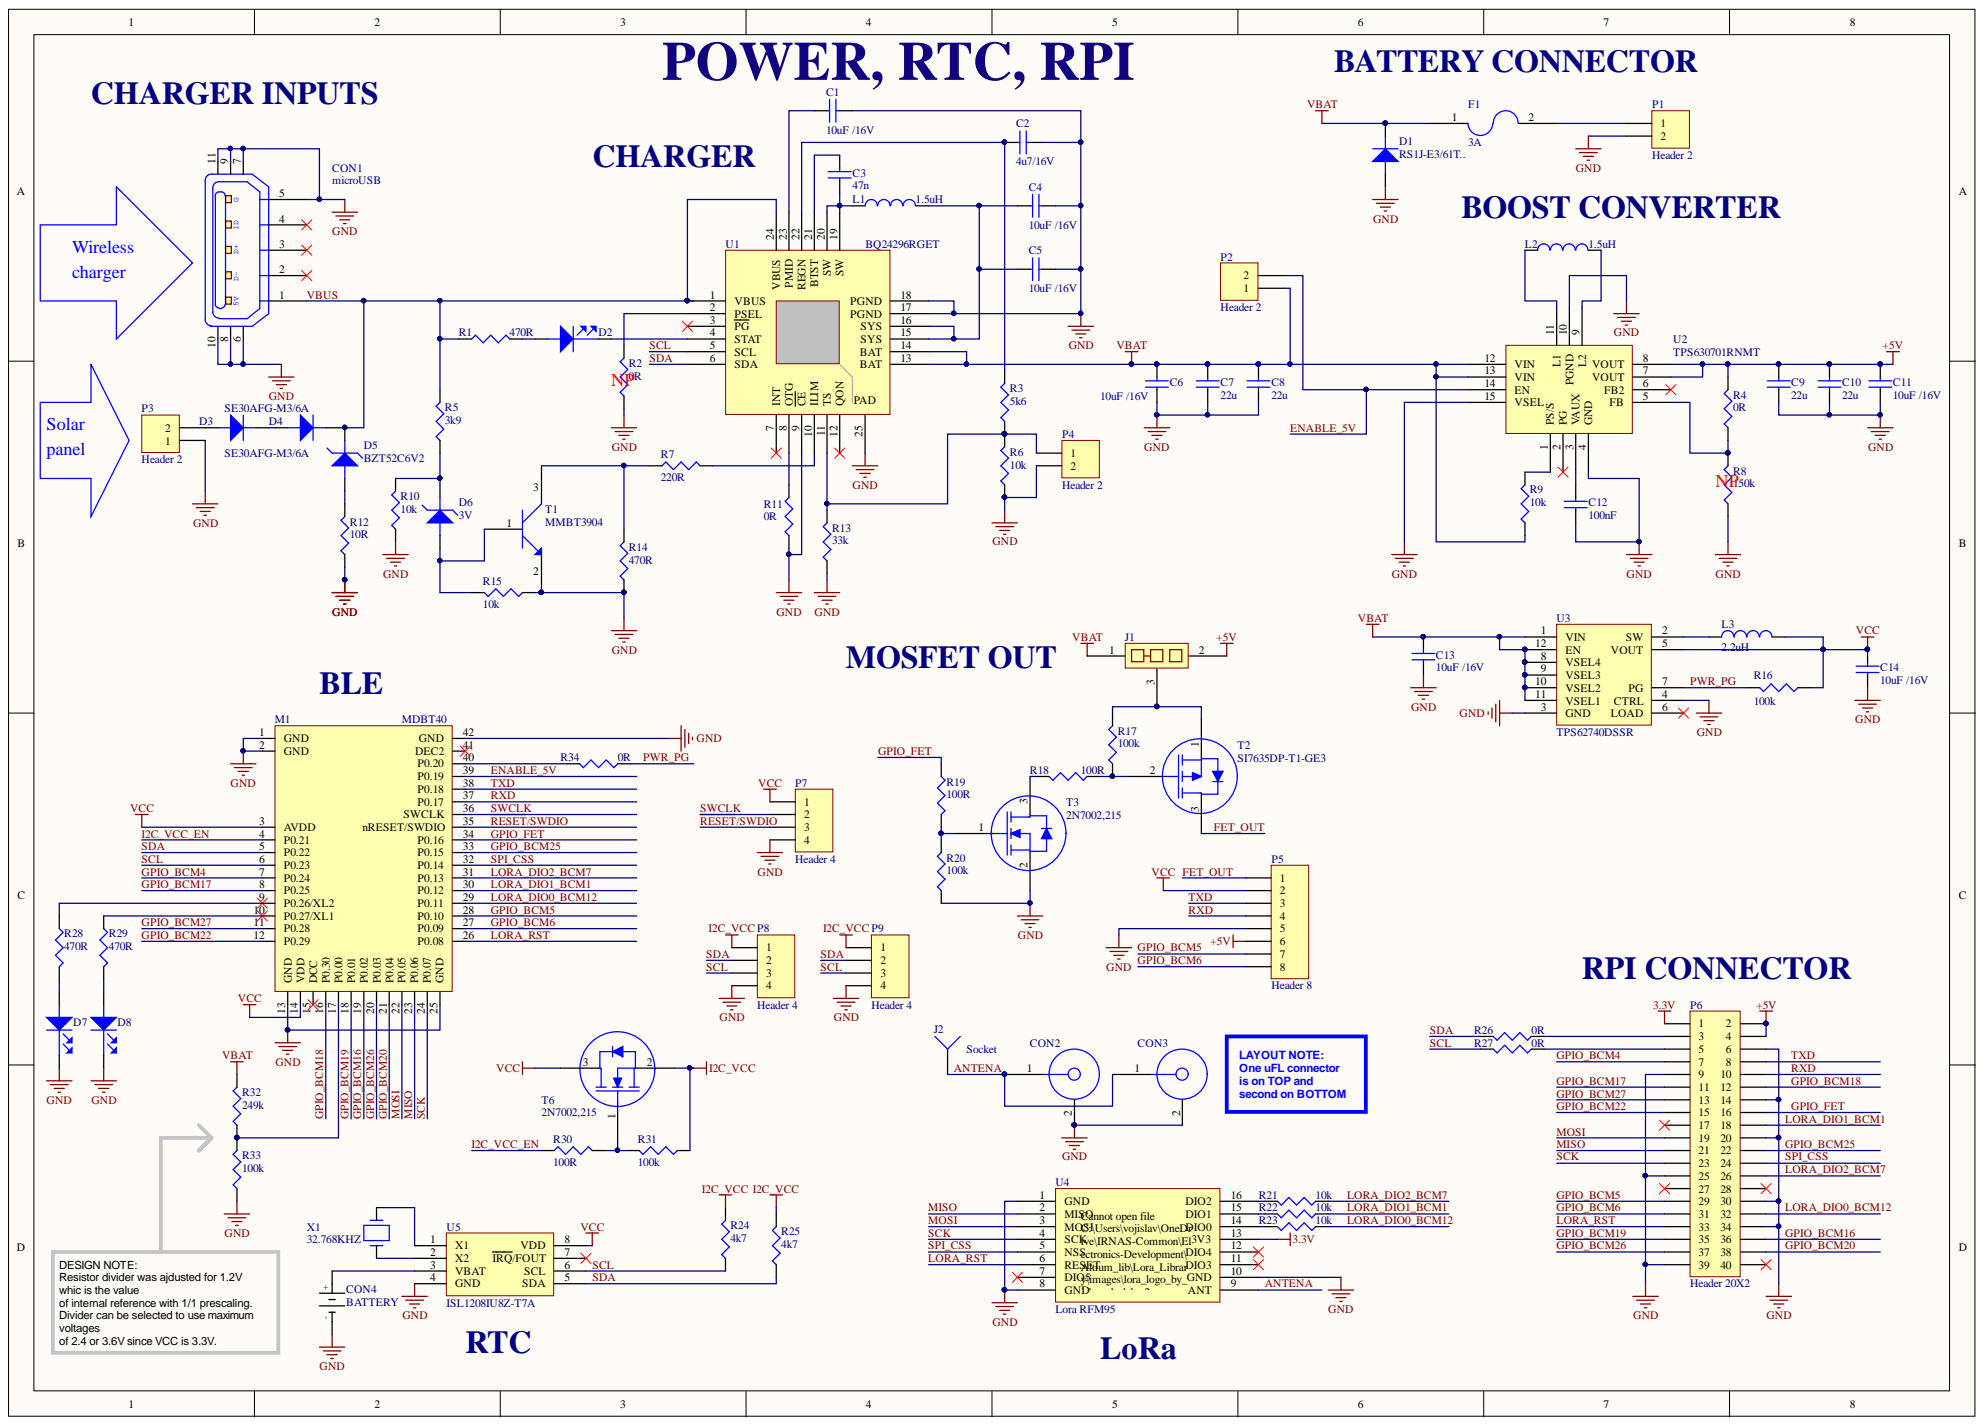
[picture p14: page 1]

SW 19 SW 20 BTST 21 REGN 22 PMID 23 VBUS 24

VIN 13

ENABLE_5V | VSEL 15

LAYOUT NOTE:
One uFL connector
is on TOP and
second on BOTTOM

Cannot open file
C:\Users\vojislav\OneDr
ive\IRNAS-Common\El
ectronics-Development\
Altium_lib\Lora_Librar
y\images\lora_logo_by_
jelgervh-dalgn2y.png
Lora RFM95

DESIGN NOTE:
Resistor divider was ajdusted for 1.2V
whic is the value
of internal reference with 1/1 prescaling.
Divider can be selected to use maximum
voltages
of 2.4 or 3.6V since VCC is 3.3V.

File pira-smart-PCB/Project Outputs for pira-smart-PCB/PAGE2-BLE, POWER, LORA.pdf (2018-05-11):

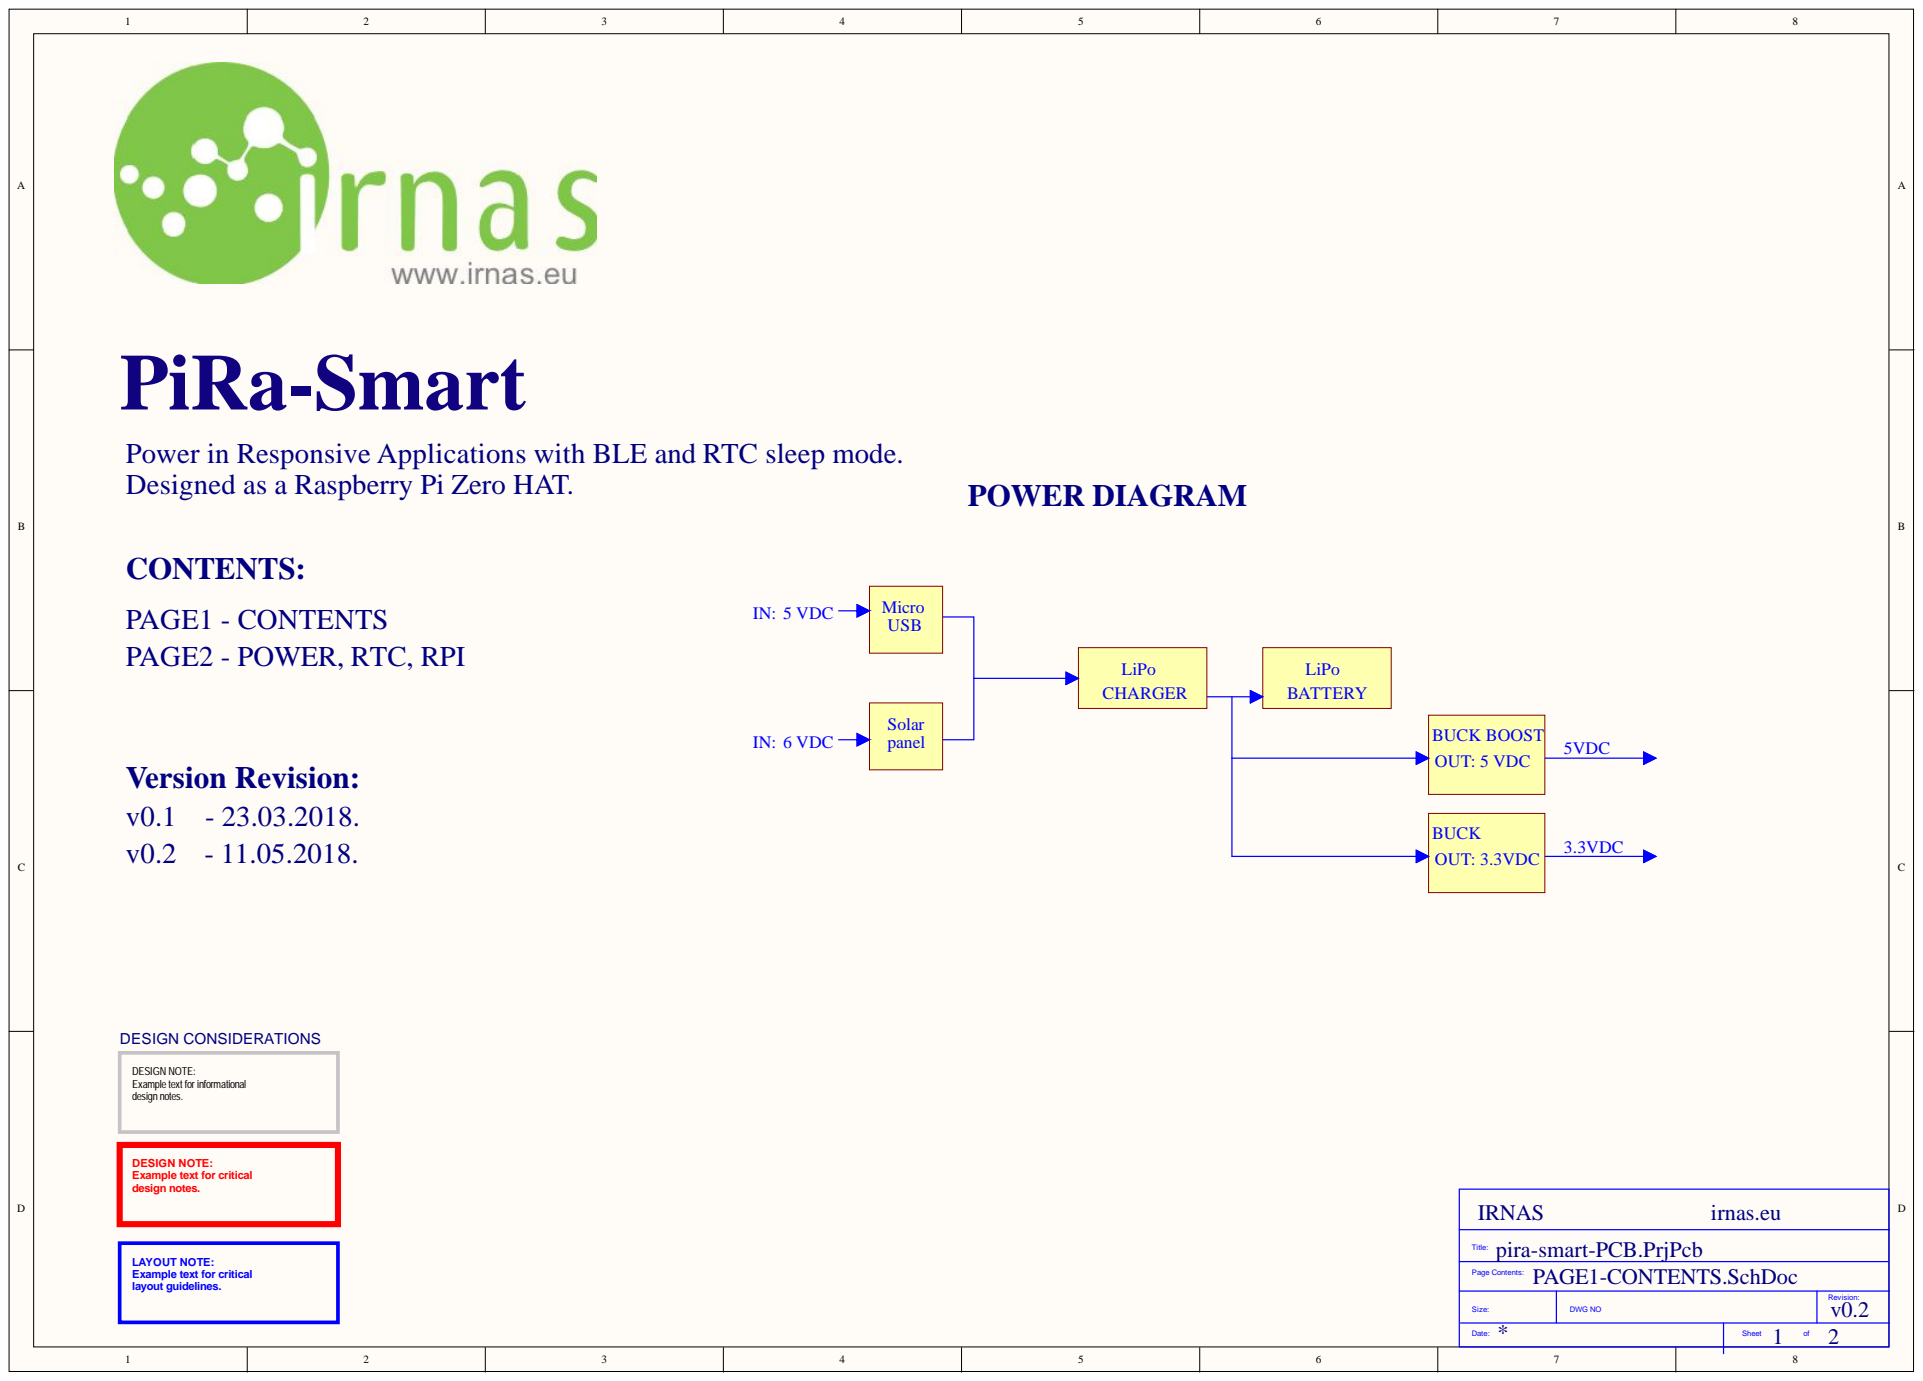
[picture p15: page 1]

Power in Responsive Applications with BLE and RTC sleep mode.
Designed as a Raspberry Pi Zero HAT.

DESIGN NOTE:
Example text for informational
design notes.

Example text for critical

pira-smart-PCB.PrjPcb
PAGE1-CONTENTS.SchDoc

LAYOUT NOTE:
layout guidelines.

Size: | DWG NO | Revision: v0.2

* Date: | 1 2 Sheet of

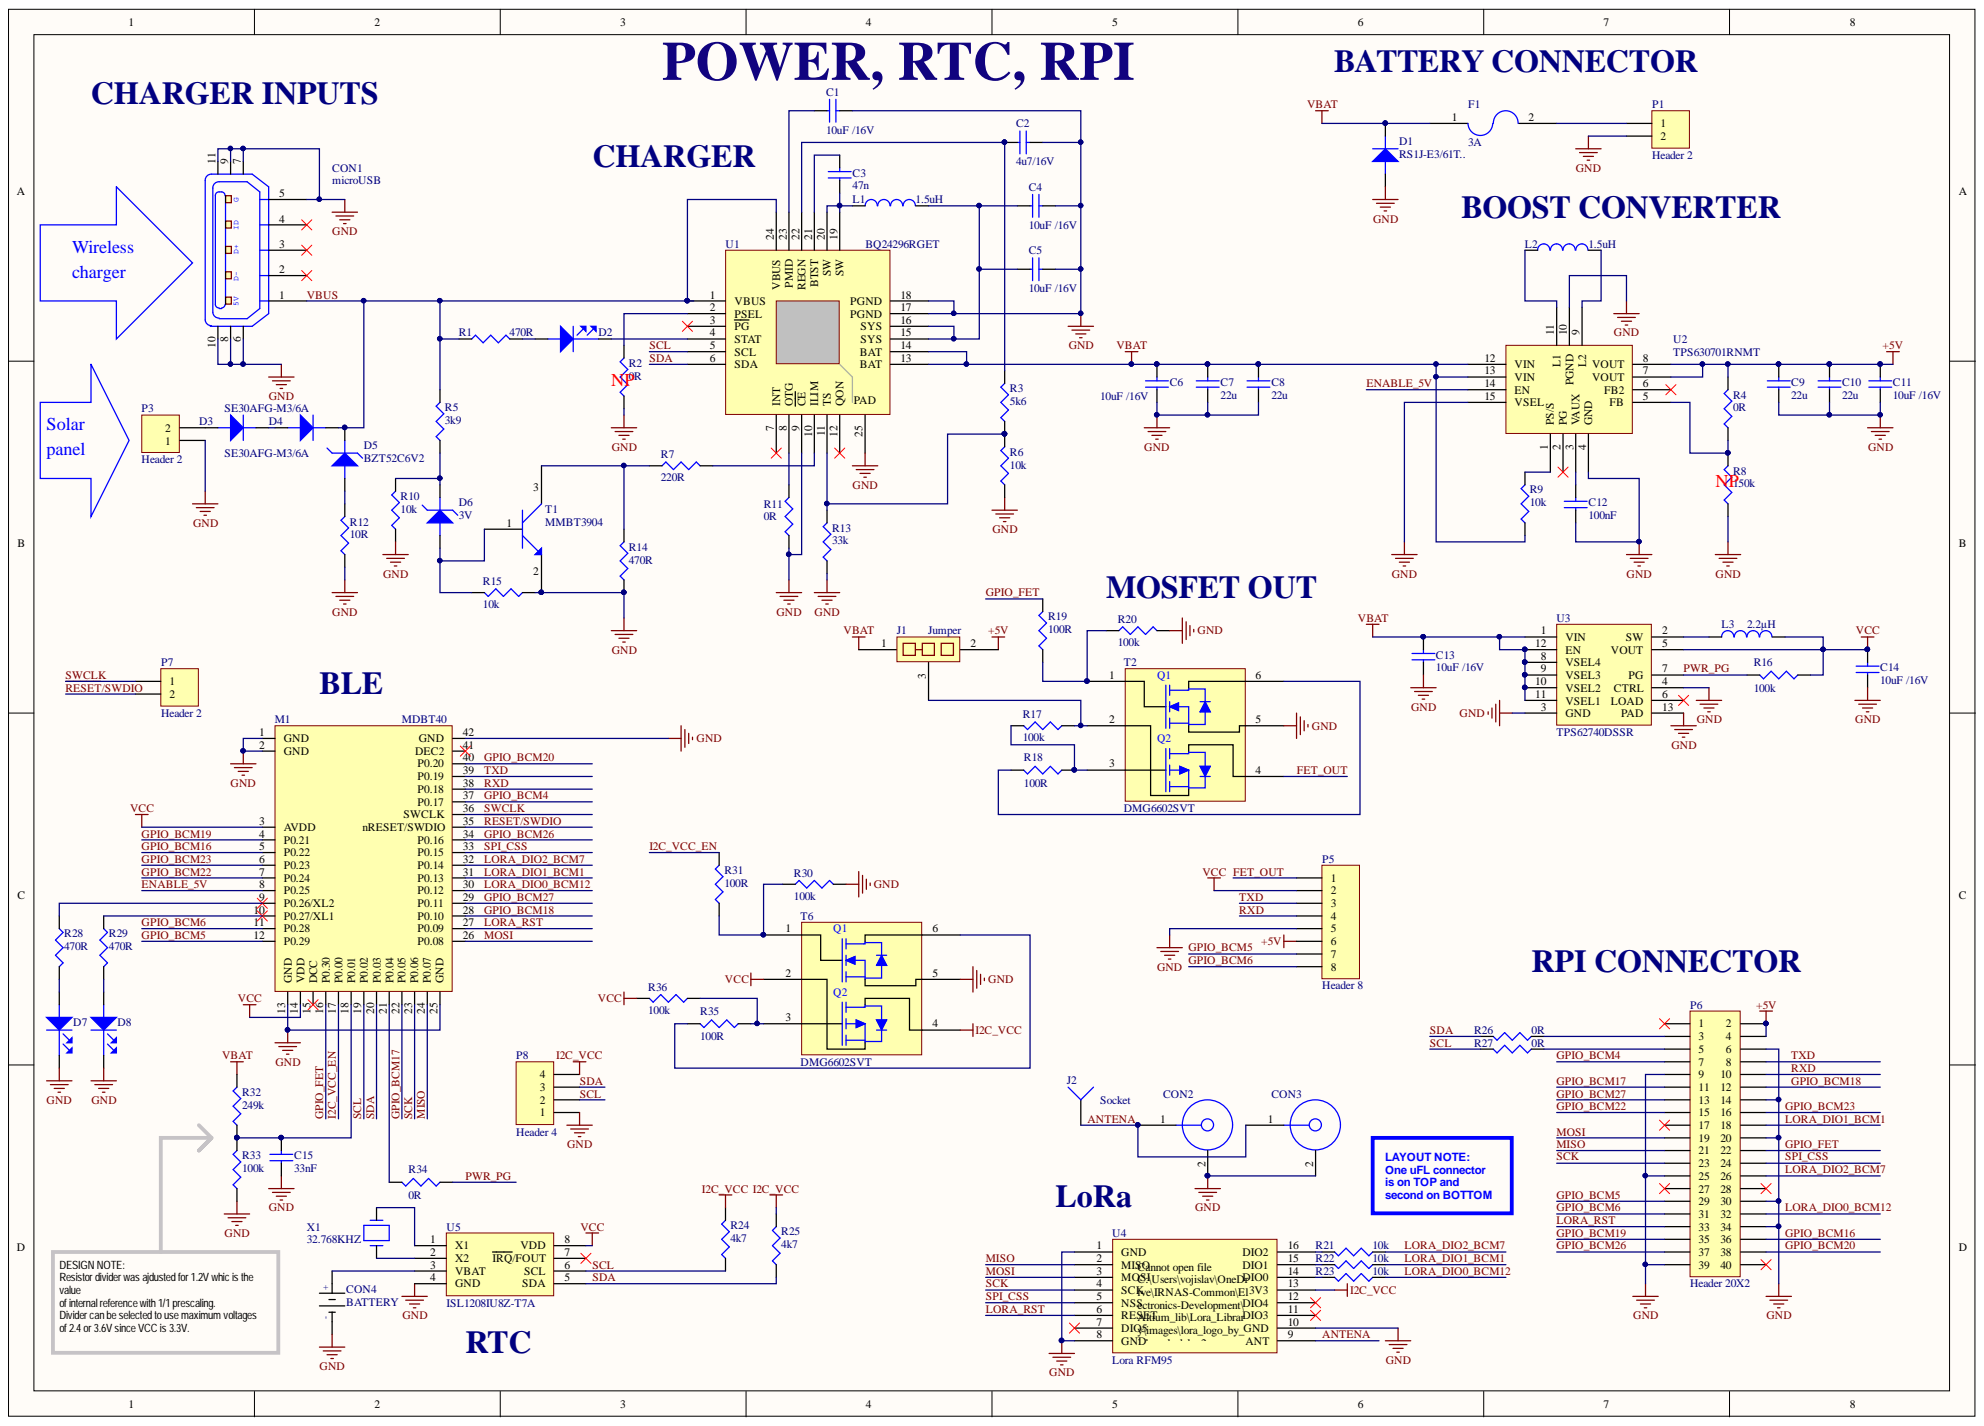
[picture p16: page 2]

SW 19 SW 20 BTST 21 REGN 22 PMID 23 VBUS 24

ENABLE_5V | VIN 13

VSEL 15

LAYOUT NOTE:
One uFL connector
is on TOP and
second on BOTTOM

DESIGN NOTE:
Resistor divider was ajdusted for 1.2V whic is the
value
of internal reference with 1/1 prescaling.
Divider can be selected to use maximum voltages
of 2.4 or 3.6V since VCC is 3.3V.

Cannot open file
C:\Users\vojislav\OneDr
ive\IRNAS-Common\El
ectronics-Development\
Altium_lib\Lora_Librar
y\images\lora_logo_by_
jelgervh-dalgn2y.png
Lora RFM95

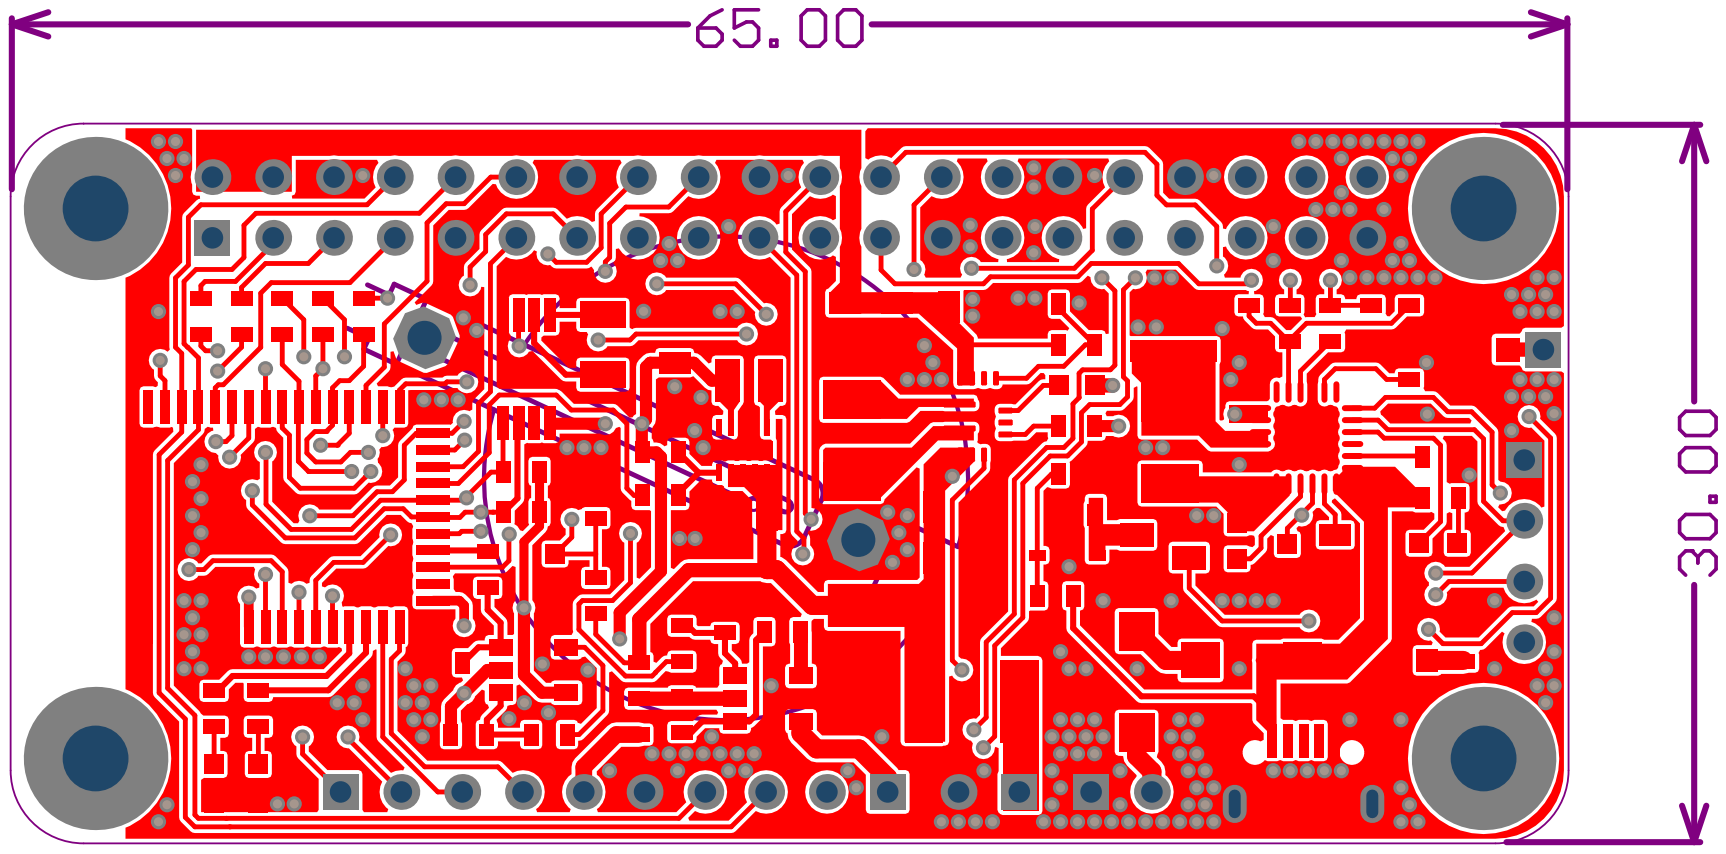
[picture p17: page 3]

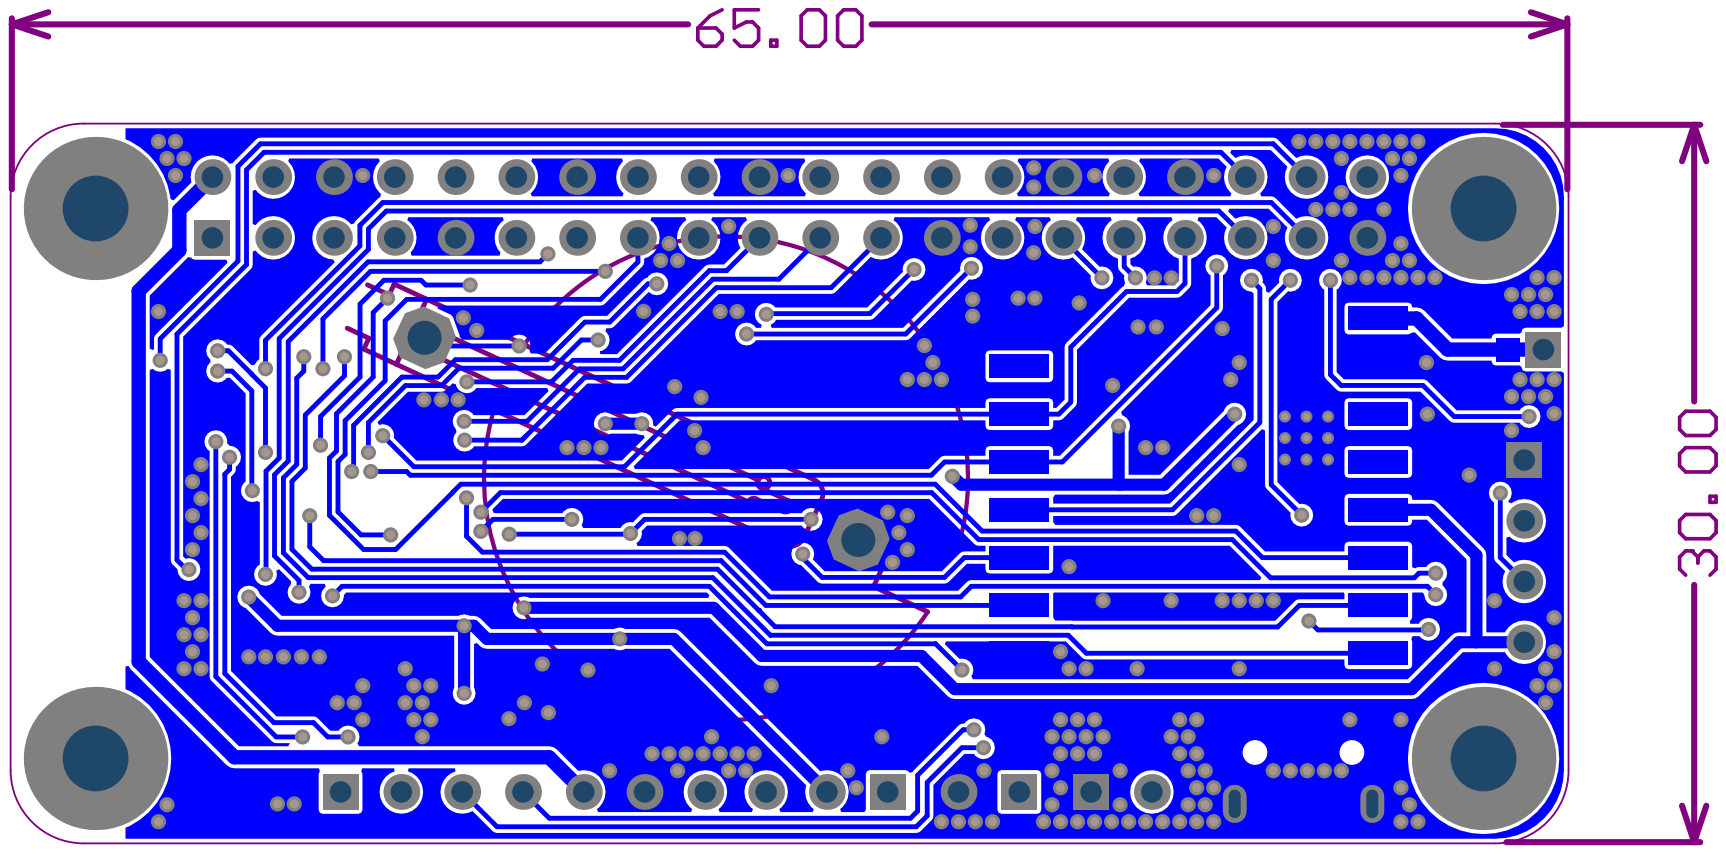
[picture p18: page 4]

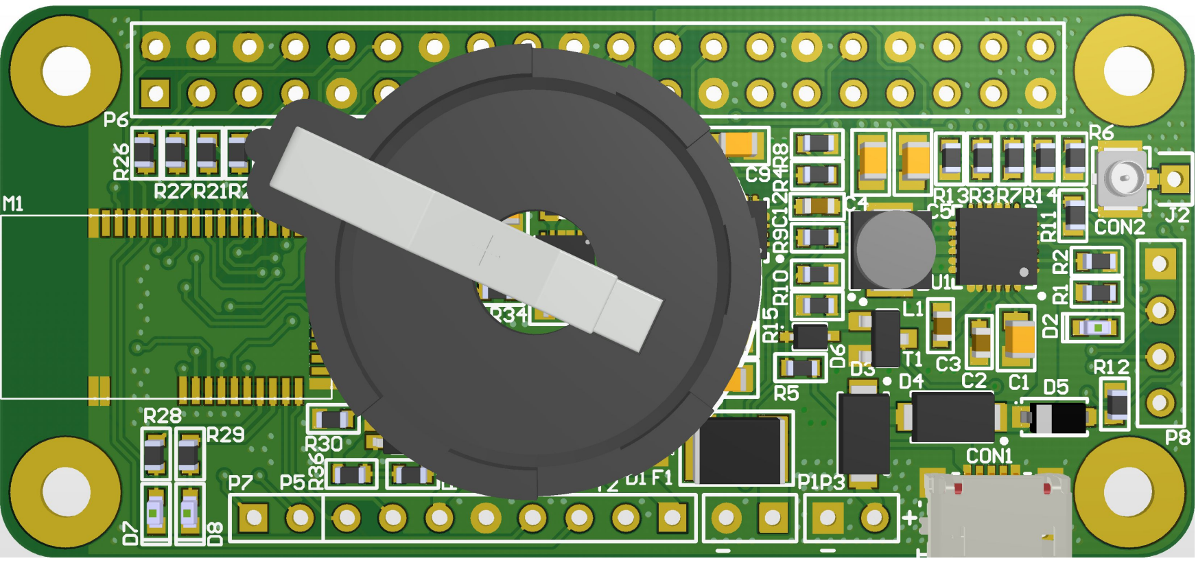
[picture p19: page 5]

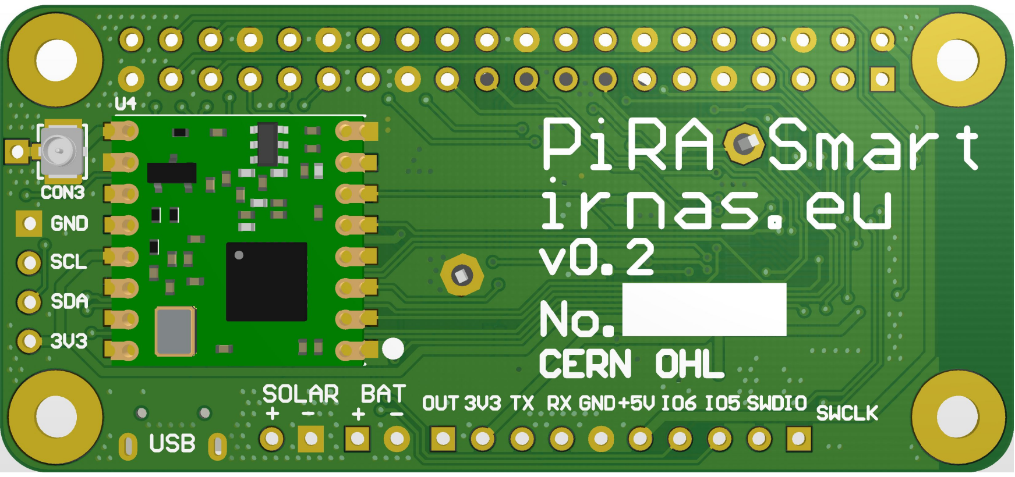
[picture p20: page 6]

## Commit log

2018-03-15 sch done for review
    [MDBT40-2D Drawing-20150402.dwg, MDBT40-2D Drawing-20150402.dxf, MDBT40-P 2D Drawing-20150402.dwg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]
2018-03-19 Updated schematic, all footprints have been added and first schematic review has been done
    [PAGE2-BLE, POWER, LORA.SchDoc, pira-smart-PCB.PrjPcb, pira-smart-pcb.PcbDoc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]
2018-03-20 Schematic completed, PCB design started, components updated.
    [PAGE1-CONTENTS.SchDoc, PAGE2-BLE, POWER, LORA.SchDoc, pira-smart-PCB.PrjPcb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]
2018-03-22 PCB placement finished, routing started
    [PAGE2-BLE, POWER, LORA.SchDoc, pira-smart-pcb.PcbDoc, pira-smart-pcblib.PcbLib]
2018-03-22 PCB modified. Some footprints, components and lines changed in schematic.
    [PAGE2-BLE, POWER, LORA.SchDoc, pira-smart-pcb.PcbDoc, pira-smart-pcblib.PcbLib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]
2018-03-23 PCB updated, cosmetic changes in schematics.
    [PAGE2-BLE, POWER, LORA.SchDoc, pira-smart-pcb.PcbDoc]
2018-03-23 PCB updated.
    [pira-smart-pcb.PcbDoc]
2018-03-26 PCB updated. Schematic component changed and schematic updated.
    [PAGE2-BLE, POWER, LORA.SchDoc, pira-smart-PCB.PrjPcb, pira-smart-pcb.PcbDoc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]
2018-03-26 PCB modified
    [pira-smart-PCB.PrjPcb, pira-smart-pcb.PcbDoc]
2018-03-28 Generated Gerber i NC Drill files, added board dimensions to PCB.
    [pira-smart-PCB.PrjPcb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]
2018-03-28 BOM generated, double power object deleted from schematics, output job updated with BOM generation settings
    [Bill of Materials production-pira-smart-PCB.xlsx, PAGE2-BLE, POWER, LORA.SchDoc]
2018-04-10 Updated output job and assembly drawings
    [Bill of Materials production-pira-smart-PCB.xlsx, Pick Place for pira-smart-pcb(V1.0 Assembly).csv, pira-smart-PCB.PrjPcb]
2018-05-10 Fixed bugs/improvements listed under GitHub Issues.
    [PAGE2-BLE, POWER, LORA.SchDoc, pira-smart-PCB.PrjPcb, pira-smart-pcb.PcbDoc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]
2018-05-11 Updated PCB and SCH to final version. Gerber and NC Drill files generated.
    [PAGE1-CONTENTS.SchDoc, PAGE2-BLE, POWER, LORA.SchDoc, pira-smart-PCB.PrjPcb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]
